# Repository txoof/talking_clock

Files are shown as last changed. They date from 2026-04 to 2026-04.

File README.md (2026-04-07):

# Talking Clock

An accessible clock that announces the time on demand or automatically at regular intervals. Designed to be built from off-the-shelf components and localized to any language that has a [Piper TTS](https://github.com/rhasspy/piper) voice model.

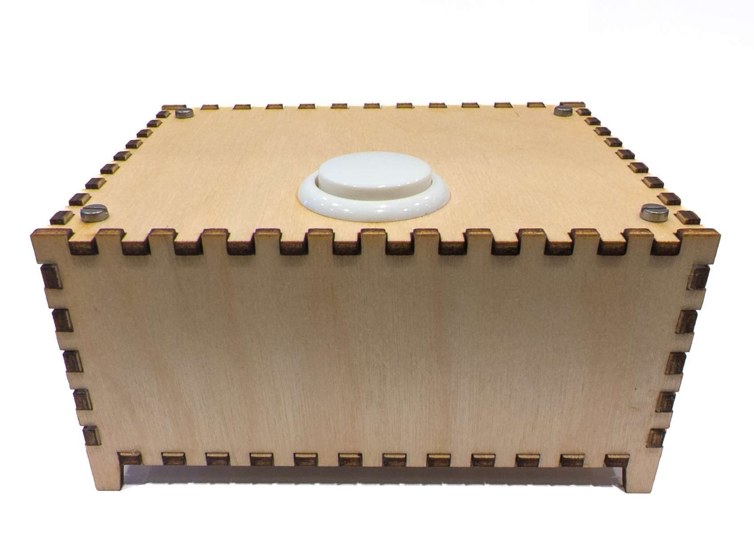
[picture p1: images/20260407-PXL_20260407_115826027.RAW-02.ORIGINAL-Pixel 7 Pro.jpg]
Clock Enclosure


## User Manual

Please see the [End User Manual](./User_Manual.md) for operation instructions.

## Overview

The clock is built around a Raspberry Pi Pico running CircuitPython. Three buttons provide the entire user interface: one to announce the time, and two for navigating settings. All audio is pre-generated and stored on an SD card, making the clock fully offline with no network dependency.

The project has three main components:

| Component | Location | Description |
| --- | --- | --- |
| Firmware | [`./clock_code/`](./clock_code/) | CircuitPython code that runs on the Pico |
| Audio tooling | [`./talking-clock-audio/`](./talking-clock-audio/) | Python CLI for generating and deploying voice packages |
| Hardware | [`./circuit/`](./circuit/) and [`./enclosure/`](./enclosure/) | Bill of materials, wiring, and laser-cut enclosure design |

## Fast Track

This is the shortest path from parts to a working clock. Each step links to the relevant README for full details.

### 1. Assemble the hardware

Build the circuit from the bill of materials and wiring diagram in the [electronics README](./electronics/README.md). The enclosure design is in the [enclosure README](./enclosure/README.md) and is optional -- the clock works without one.

### 2. Install CircuitPython and firmware

Follow the [clock firmware README](./clock_code/README.md) to install CircuitPython 10.x on the Pico, copy the firmware files, and prepare the SD card with the bundled audio assets.

### 3. Deploy a voice package

Voice packages are included in the repository. Connect the SD card to your computer and run:

```bash
cd talking-clock-audio
python -m venv venv
source venv/bin/activate
pip install -e .
tca deploy
```

Select the SD card volume and choose the packages to copy. The default firmware configuration expects a voice package named `en_US_lessac_medium`. See the [talking-clock-audio README](./talking-clock-audio/README.md) for the full workflow including generating packages for other languages.

### 4. First boot

Insert the SD card and power on the clock. The firmware will create a default `config.json` on the SD card automatically. Press ANNOUNCE to hear the time. Hold PLUS or MINUS for 1.5 seconds to open the settings menu and set the correct time.

## Localization

The clock supports any language that has a Piper TTS voice model on Hugging Face. Adding a new language requires creating a YAML phrase configuration file and generating a voice package with the `tca` tool. See the [talking-clock-audio README](./talking-clock-audio/README.md) for the full workflow, including an LLM-assisted tool for building YAML configurations for languages you are not fluent in.

## Repository Structure

```text
talking-clock/
  clock_code/              # CircuitPython firmware and SD card audio assets
  talking-clock-audio/     # tca CLI for generating and deploying voice packages
  electronics/             # Bill of materials, wiring, and schematics
  enclosure/               # Laser-cut enclosure OpenSCAD design and assets
```

## Attributions

### Audio Files

| Asset | Attribution |
| ----- | --- |
| [volume_boop.wav](./clock_code/sd_card/audio_assets/volume_boop.wav) | [546974__finix473__ui_click](https://freesound.org/people/finix473/sounds/546974/) |
| [alarms/accepted-sweet.wav](./clock_code/sd_card/audio_assets/alarms/accepted-sweet.wav) | [akelley6](https://freesound.org/people/akelley6/packs/44231/) |
| [alarms/adventure-harp.wav](./clock_code/sd_card/audio_assets/alarms/adventure-harp.wav) | [akelley6](https://freesound.org/people/akelley6/packs/44231/) |
| [alarms/bell-motif.wav](./clock_code/sd_card/audio_assets/alarms/bell-motif.wav) | [akelley6](https://freesound.org/people/akelley6/packs/44231/) |
| [alarms/sine-aww.wav](./clock_code/sd_card/audio_assets/alarms/sine-aww.wav) | [akelley6](https://freesound.org/people/akelley6/packs/44231/) |
| [alarms/sine-cellular.wav](./clock_code/sd_card/audio_assets/alarms/sine-cellular.wav) | [akelley6](https://freesound.org/people/akelley6/packs/44231/) |
| [alarms/welcome-home-synth.wav](./clock_code/sd_card/audio_assets/alarms/welcome-home-synth.wav) | [akelley6](https://freesound.org/people/akelley6/packs/44231/) |
| [alarms/xd-mewtwo.wav](./clock_code/sd_card/audio_assets/alarms/xd-mewtwo.wav) | [akelley6](https://freesound.org/people/akelley6/packs/44231/) |
| [alarms/xmas-miracle.wav](./clock_code/sd_card/audio_assets/alarms/xmas-miracle.wav) | [akelley6](https://freesound.org/people/akelley6/packs/44231/) |
## License

GPL-3.0-or-later

## Contributing

Contributions are welcome, especially new language configurations, voice model recommendations, hardware improvements, and enclosure designs. Open an issue or pull request on [GitHub](https://github.com/txoof/talking-clock).

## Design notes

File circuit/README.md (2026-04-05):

# Talking Clock Electronics

This document covers the electronic components, wiring, and known hardware gotchas for the Talking Clock project.

- [Talking Clock Electronics](#talking-clock-electronics)
  - [Overview](#overview)
  - [Bill of Materials](#bill-of-materials)
  - [Wiring](#wiring)
  - [Known Hardware Gotchas](#known-hardware-gotchas)

## Overview

The clock is built around a Raspberry Pi Pico (RP2040) running CircuitPython. A DS3231 RTC module keeps accurate time over power cycles. Audio is generated by the Pico and driven through a MAX98357A I2S amplifier to a small full-range speaker. Three buttons provide the user interface. All voice audio and configuration files are stored on an SD card.

All components are off-the-shelf and sourceable from standard electronics suppliers. No custom PCB is required.

## Bill of Materials

### Electronics

| Part | Specifications | Notes | Link |
| ---- | --- | ----- | ---- |
| Raspberry Pi Pico | RP2040 | Pico or Pico W | |
| SPI SD Card Reader | 3.3V-5V Level Shifted | | [TinyTronics 000375](https://www.tinytronics.nl/en/data-storage/modules/microsd-card-adapter-module-3.3v-5v-with-level-shifter) |
| I2C DS3231 RTC Module | | Requires CR2032 battery | [TinyTronics 005849](https://www.tinytronics.nl/en/sensors/time/keyestudio-ds3231-rtc-module-i2c) |
| CR2032 Battery | | For RTC backup power | |
| I2S MAX98357A Amplifier | 3W | Clones available | [Adafruit 3006](https://www.adafruit.com/product/3006) |
| Mono Speaker | 4 ohm 3W full-range | Enclosed speaker has superior sound | |
| Arcade Button | 30mm | Main ANNOUNCE button | [Kiwi Electronics](https://www.kiwi-electronics.com/en/30mm-arcade-button-black-3860) |
| Momentary Push Button Switch | Panel Mount 37x14x14mm | 2x required, PLUS and MINUS | [Conrad.com](https://www.conrad.com/en/p/tru-components-tc-dt310ws-tc-dt310ws-pushbutton-momentary-1-pc-s-1589423.html) |
| 2.54mm Pitch Strip Board | | For VCC/GND bus bar | |
| 2.54mm Pin Headers | 2x9 | Bus bar for VCC and GND | |

## Wiring

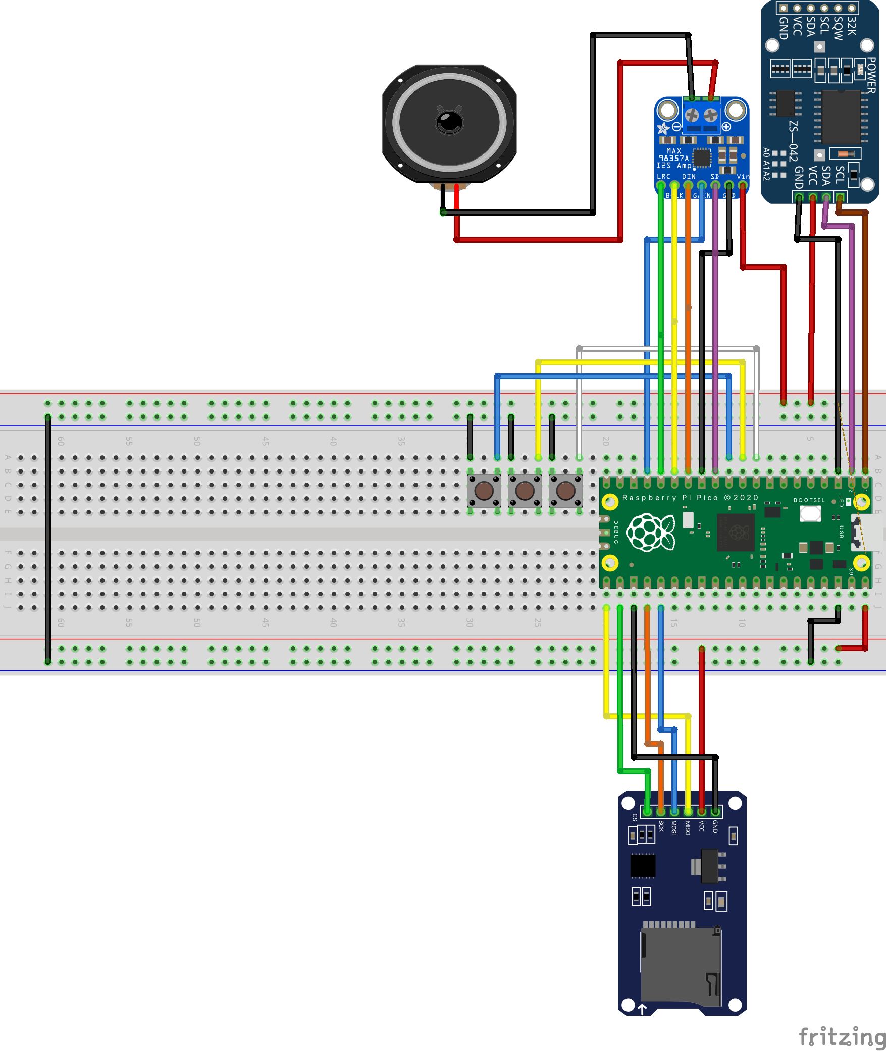
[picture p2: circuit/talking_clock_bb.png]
Bread Board Image


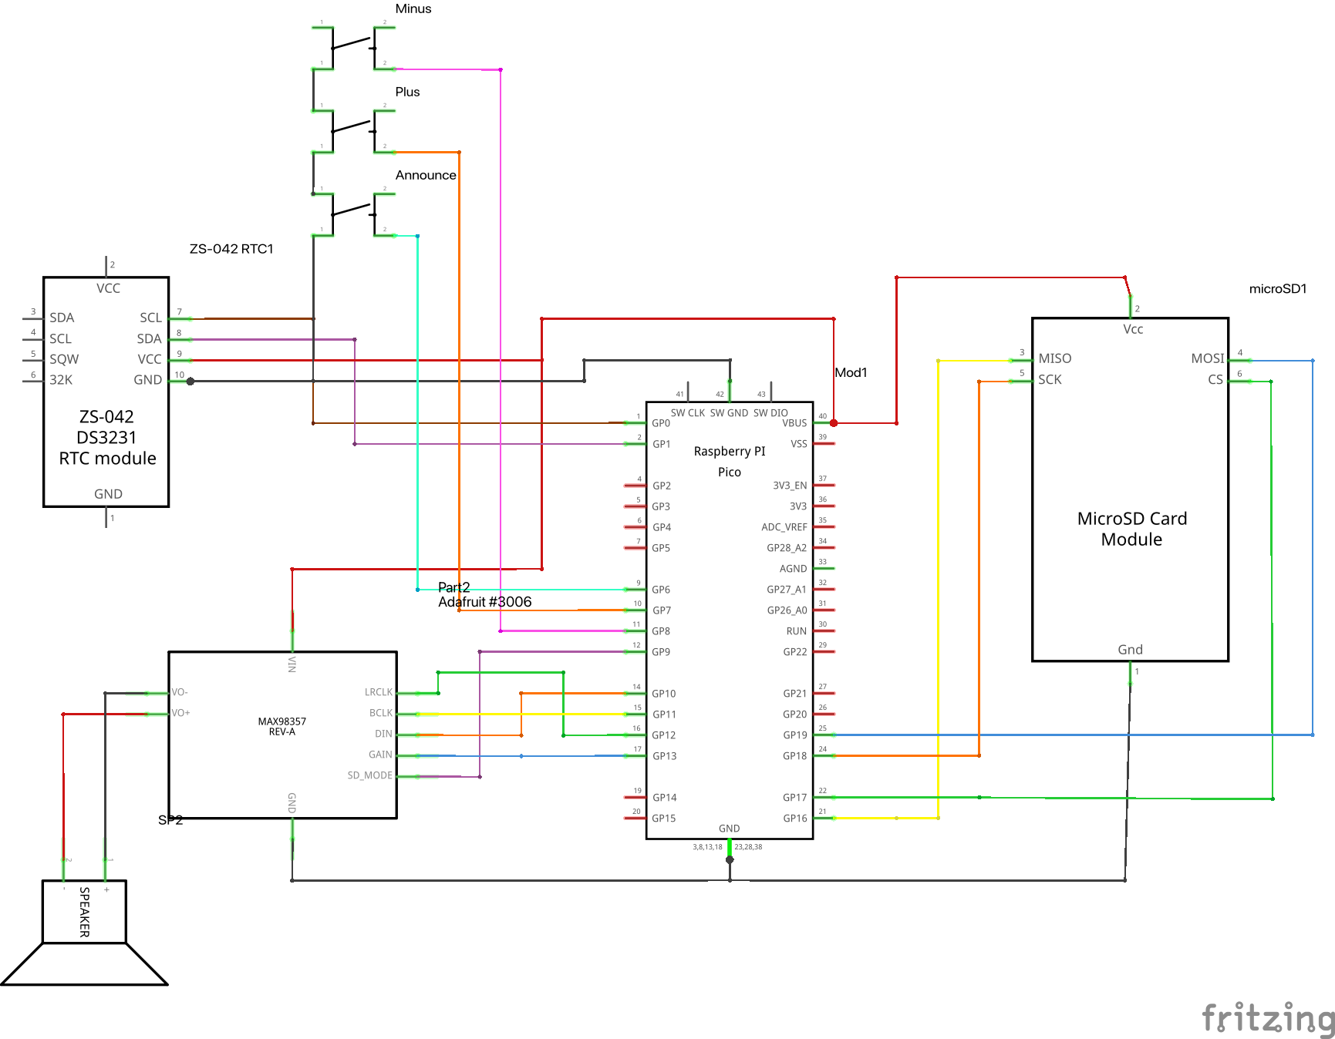
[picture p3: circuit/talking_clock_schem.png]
Wiring Schematic


[Fritzing](https://fritzing.org/download/) [`talking_clock.fzz`](./talking_clock.fzz)

### Pin assignments

| Signal | Pico Pin | Notes |
| --- | --- | ----- |
| I2C SDA (RTC) | GP0 | |
| I2C SCL (RTC) | GP1 | |
| I2S Data | GP10 | MAX98357A DIN |
| I2S Bit Clock | GP11 | MAX98357A BCLK |
| I2S Word Select | GP12 | MAX98357A LRC |
| Amp GAIN | GP13 | Driven high for 9dB gain |
| SD MISO | GP16 | |
| SD CS | GP17 | |
| SD CLK | GP18 | |
| SD MOSI | GP19 | |
| ANNOUNCE Button | GP6 | Pulled up, active low |
| PLUS Button | GP7 | Pulled up, active low |
| MINUS Button | GP8 | Pulled up, active low |
| Amp SD (shutdown) | GP9 | Must be driven high |

### Bus bar

A 2x9 pin header soldered to strip board provides a shared VCC and GND bus for components that do not terminate directly at the Pico. One column carries 3.3V and the other carries GND. The push button switches and any other components requiring a common ground connect here.

## Known Hardware Gotchas

### MAX98357A SD pin must be driven high

The SD pin on the MAX98357A controls the shutdown state of the amplifier. If left floating, the pin state is undefined and the amplifier will intermittently shut down, producing random pops and dropouts that are easy to mistake for a software or speaker problem.

GP9 must be configured as an output and driven high at boot before any audio is played:

```python
sd = digitalio.DigitalInOut(board.GP9)
sd.direction = digitalio.Direction.OUTPUT
sd.value = True
```

### I2C pin assignment

The DS3231 RTC uses I2C on GP0 and GP1. The assignment is SCL on GP1 and SDA on GP0, which is the reverse of what some wiring diagrams show. Using the wrong assignment will cause the RTC to fail silently at boot.

### GAIN pin configuration

The MAX98357A GAIN pin sets the amplifier gain. Leaving it floating selects 9dB gain, which is appropriate for this application. Do not connect GAIN to GND (15dB) or VDD (12dB) unless you have a specific reason to change the gain level.

### Speaker selection

Sensitivity and enclosure matter as much as power rating. A speaker rated at 85 dB/W/m or better in a proper full-range enclosure will sound significantly better than a bare driver of the same wattage. The high-pass filter in the audio generation pipeline removes low-frequency content that small drivers cannot reproduce, but it cannot compensate for a poorly chosen or unenclosed speaker.

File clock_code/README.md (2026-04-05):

# Talking Clock Firmware

This directory contains the CircuitPython firmware for the Talking Clock and all files that need to be deployed to the Pico and SD card.

## Requirements

### CircuitPython

The clock requires CircuitPython 10.x. The firmware was developed and tested against CircuitPython 10.1.4 on the Raspberry Pi Pico (RP2040).

To check the version currently installed on your Pico, connect it via USB and read `boot_out.txt` from the CIRCUITPY drive, or connect with mpremote and run:

```python
import sys
print(sys.version)
```

To install or update CircuitPython, download the UF2 file for the Raspberry Pi Pico from [circuitpython.org](https://circuitpython.org/board/raspberry_pi_pico/) and follow the instructions there.

It is best to prepare the Pico with CircuitPython prior to installing it in the enclosure!

### Libraries

The following Adafruit libraries are required:

```text
adafruit_ds3231==2.4.26
adafruit_bus_device==5.2.15
adafruit_register==1.11.1
```

Pre-compiled `.mpy` versions are included in `./lib/` and should be copied to the `lib/` directory on the CIRCUITPY drive. See the Installation section below.

## File Layout

Files are split between two destinations: the CIRCUITPY drive (the Pico itself) and the SD card.

### What goes on the Pico (CIRCUITPY)

Copy these files and directories to the root of the CIRCUITPY drive:

```text
code.py
menu.py
menu.json
debug_mode.py
pico_rules.py
voices.py
lib/
  adafruit_bus_device/
  adafruit_ds3231.mpy
  adafruit_register/
```

Do not copy `README.md`, `requirements.txt`, `sd_card/`, `libArchive/`, `stubArchive/`, or `__pycache__/` to the Pico.

### What goes on the SD card

The SD card must be formatted as FAT32 with the volume label `TALK-CLOCK`. Copy the contents of `./sd_card/` to the root of the SD card:

```text
audio_assets/
  volume_boop.wav          # played on volume change confirmation
  beep.wav                 # played during button hold-repeat in time setting
  alarms/                  # alarm tone WAV files
    accepted-sweet.wav
    adventure-harp.wav
    bell-motif.wav
    sine-aww.wav
    sine-cellular.wav
    welcome-home-synth.wav
    xd-mewtwo.wav
    xmas-miracle.wav
```

Voice packages are  included in the repository. They can be added to the SD card using `tca deploy`. See [Adding Voice Models](#adding-voice-models) below.

## Installation

### 1. Install CircuitPython

Download the UF2 file for the Raspberry Pi Pico from [circuitpython.org](https://circuitpython.org/board/raspberry_pi_pico/). Hold the BOOTSEL button on the Pico while connecting it via USB. It will mount as a drive called RPI-RP2. Copy the UF2 file to that drive. The Pico will reboot and mount as CIRCUITPY.

### 2. Install libraries

The required libraries are included in `./lib/`. Copy the entire `lib/` directory to the root of the CIRCUITPY drive:

```bash
cp -r ./lib /Volumes/CIRCUITPY/lib
```

Alternatively, install them using [circup](https://github.com/adafruit/circup), Adafruit's CircuitPython library manager:

```bash
pip install circup
circup install adafruit_ds3231 adafruit_bus_device adafruit_register
```

### 3. Copy firmware files

Copy the following files to the root of the CIRCUITPY drive:

```bash
cp code.py menu.py menu.json debug_mode.py pico_rules.py voices.py /Volumes/CIRCUITPY/
```

The Pico will restart automatically when `code.py` is copied or updated.

### 4. Prepare the SD card

Format the SD card as FAT32 and set the volume label to `TALK-CLOCK`. Copy the audio assets to the SD card:

```bash
cp -r ./sd_card/audio_assets /Volumes/TALK-CLOCK/audio_assets
```

Insert the SD card into the clock.

### Adding voice models

The clock requires at least one voice package on the SD card to announce the time. Voice packages are generated from Piper TTS voice models using the `tca` command-line tool included in the `talking-clock-audio/` directory of this repository.

See the [talking-clock-audio README](../talking-clock-audio/README.md) for the full workflow covering downloading voice models, generating audio packages, and deploying them to the SD card.

A minimal setup requires one voice package. The default voice expected by the firmware is `en_US_lessac_medium`. 

## Configuration

The firmware reads configuration from `/sd/config.json` on the SD card. This file is created automatically on first boot with default values if it does not exist. It is updated automatically when settings are changed through the menu.

### config.json reference

| Key | Default | Description |
| --- | --- | --- |
| `volume_step` | `7` | Volume level from 0 (silent) to 10 (maximum) |
| `voice` | `"en_US_lessac_medium"` | Name of the active voice package directory on the SD card |
| `mode` | `"standard"` | Time announcement mode: `operational`, `broadcast`, `standard`, or `casual` |
| `alarm_enabled` | `false` | Whether the alarm is active |
| `alarm_hour` | `7` | Alarm hour in 24-hour format |
| `alarm_minute` | `0` | Alarm minute |
| `alarm_tone` | `"/sd/audio_assets/volume_boop.wav"` | Path to the alarm tone WAV file |
| `announce_interval` | `"off"` | Auto-announce interval: `"off"`, `"hourly"`, `"half"`, or `"quarter"` |

## Using the Clock

### Button interface

The clock has three buttons: ANNOUNCE, PLUS, and MINUS.

| Button | Normal mode | In a menu |
| --- | --- | --- |
| ANNOUNCE | Announce the current time | Confirm selection |
| PLUS (short) | Volume up | Scroll forward |
| MINUS (short) | Volume down | Scroll back |
| PLUS or MINUS (hold 1.5s) | Open settings menu | Exit menu |

Volume changes are confirmed with a short beep and saved automatically after 5.5 seconds of inactivity.

### Menu navigation

Open the menu by holding PLUS or MINUS for 1.5 seconds. The clock announces the name of each menu item as you scroll. Press ANNOUNCE to confirm a selection. Any long press exits the menu.

The menu contains the following items in order:

| Item | Description |
| --- | --- |
| Set time | Set the current hour and minute on the RTC |
| Set alarm | Set the alarm hour and minute |
| Enable alarm | Toggle the alarm on or off |
| Alarm tone | Cycle through available alarm tones |
| Announcement interval | Set auto-announce to off, hourly, half-hourly, or quarterly |
| Time format | Cycle through available announcement modes |
| Voice | Cycle through available voice packages |

The menu closes automatically after 30 seconds of inactivity.

### Setting the time

Open the menu and select "Set time". The clock announces the current hour. Use PLUS and MINUS to adjust, holding for faster scrolling. Press ANNOUNCE to confirm the hour and move to minutes. Press ANNOUNCE again to save and return to normal mode. Time entry times out after 30 seconds of inactivity.

### Debug output

The firmware prints status and diagnostic information to the serial console. Connect via USB and open a serial terminal (115200 baud) or use mpremote to see output:

```bash
mpremote connect auto
```

Useful output includes the current version, loaded voice and mode, RTC time at boot, rule loading results, and any errors encountered during audio playback or SD card access.

## Troubleshooting

**Clock does not boot or CIRCUITPY does not appear**

Check that CircuitPython is installed. Hold BOOTSEL while connecting USB to enter bootloader mode, then reinstall the UF2.

**"SD card mounted" does not appear in serial output**

The SD card is not being detected. Check that the card is formatted as FAT32, fully inserted, and that the SPI wiring is correct. See the electronics README for pin assignments.

**No audio plays**

Check that at least one voice package exists on the SD card and that the `voice` key in `config.json` matches the directory name exactly. Check that the MAX98357A SD pin (GP9) is wired correctly -- see the electronics README for the known hardware gotcha regarding this pin.

**Time is wrong after a power cycle**

The RTC battery may be missing or flat. The DS3231 module requires a CR2032 battery to maintain time when the clock is unpowered. Set the time through the menu after replacing the battery.

**Audio is distorted, buzzes or is clipped**

Regenerate the voice package with adjusted processing settings. See the [talking-clock-audio README](../talking-clock-audio/README.md) for tuning the high-pass filter and soft limiter.

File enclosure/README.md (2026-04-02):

# Prototype Clock Enclosure

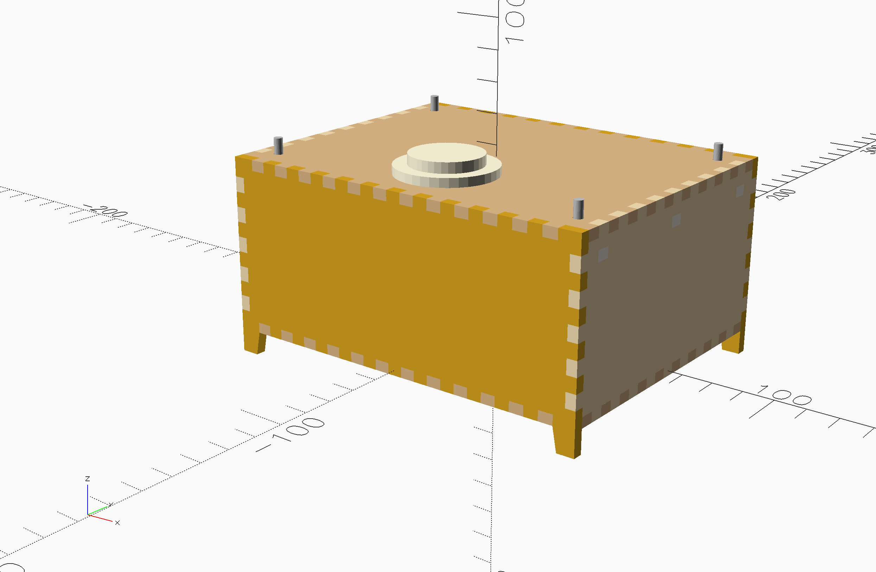
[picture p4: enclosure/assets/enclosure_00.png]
Clock Enclosure Rendering

Speaking Clock Enclosure

The prototype enclosure can be laser cut and assembled only with glue and some basic tools. The design is not beginner friendly and is a starting point for future designers.

**NOTE:** The [`clock.scad`](./clock.scad) file that is provided is set up for a 3D view. The front and top panels are commented out. This is to aide in visualizing placement of components. The missing panels in the 3D rendering will not affect the rendering of the 2D SVG for cutting.

## Laser Cut Enclosure

This model is provided as a customizable OpenSCAD model. It can be customized to work with any thickness plywood, but works best with 3.5-4.0mm wood. Switch openings, speaker grill and other features are all customizable. See the relevant headings in the OpenSCAD code.

Before cutting this, check your material thickness and update the material thickness under the *Enclosure Dimensions* heading. All values are provided in millimeters.

To prepare for laser cutting do the following:

1. Adjust the material thickness value either in the code or the [OpenSCAD Customizer](https://en.wikibooks.org/wiki/OpenSCAD_User_Manual/Customizer)
2. Set rendering mode `three d` to `0` 
3. In the OpenSCAD interface, choose **Design > Render** to produce a valid, exportable 2D object
4. Finally save the design as an SVG with **File > Export > SVG**

The resulting SVG file has a 20x10 mm benchmark rectangle in the lower right corner (Quadrant IV) that is useful for verifying that the SVG was produced with appropriate scaling.

## Assembly

### Materials

| Material | Qty | Purpose | Notes |
| --- | --- | --- | --- |
| M3x16mm Bolts | 4 | Securing Lid | This is based on a material thickness of 4mm |
| M3x10mm bolts | 2 | Securing Speaker | |
| M3 Nuts | 6 | Securing Lid and Speaker | |
| 4mm Laser Safe Ply | | | |
| Wood Glue | | | |
| 2.5mm screws | | | |
| 2.54 pitch strip board | | | |
| Dupont Headers | 2x9 | Bus Bar for VCC and GND  | Use fiberglass copper strip board with continuous strips |

### Procedure

#### Make a Bus Bar

You will need a 9x2 2.54 bus bar for VCC and Ground connections.

Create a bus bar using 2.54 pitch strip board with two columns of 9 pins. one side of the bus is for all 5v VCC connections and the other for ground connections that do not terminate at the Pico (e.g. push button switches).

#### Make Nut Sandwiches

Make two "nut sandwiches" using two long thin pieces with round holes and one long thin piece with two m3 sized holes and fingers.

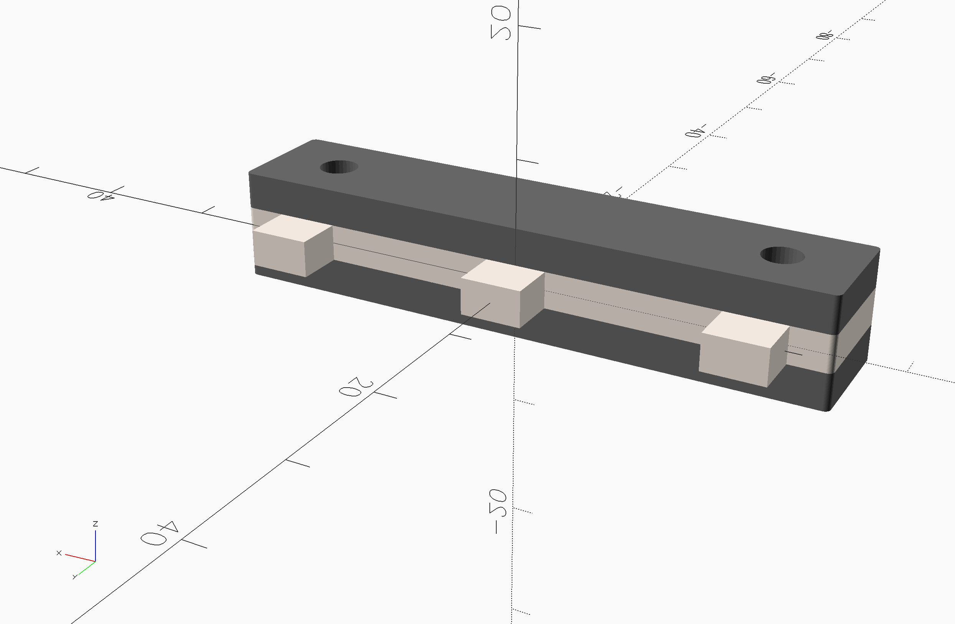
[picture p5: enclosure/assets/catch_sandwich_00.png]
Catch Sandwich Rendering


1. Spread glue on one of the pieces with round holes
2. Add the piece with hexagonal holes and drop in an m3 nut, taking care not to get glue into the threads
3. Spread glue on the top of the middle layer and add the top layer
4. While the glue is still wet, use bolts through the holes to keep the pieces aligned
5. Clamp the pieces together using additional nuts, or a clamp
6. Set aside to dry

#### Assemble Case

1. Drill holes for speaker bolts if necessary
2. Apply glue to fingers for sides, bottom, front and back. DO NOT GLUE LID!
3. Use the small rectangular plates for mounting the various IC boards using 2.5mm screws
4. Glue the various IC boards inside the enclosure in the approximate locations shown
5. Bolt or secure speaker into case as appropriate
6. Take care to align the Pi Pico with the opening in the rear and the SD card with the card OUTSIDE the enclosure
7. Glue the Nut Sandwiches into the three holes on the top of the left and right sides
8. Secure the lid by threading a bolt through the lid and into the captive nuts

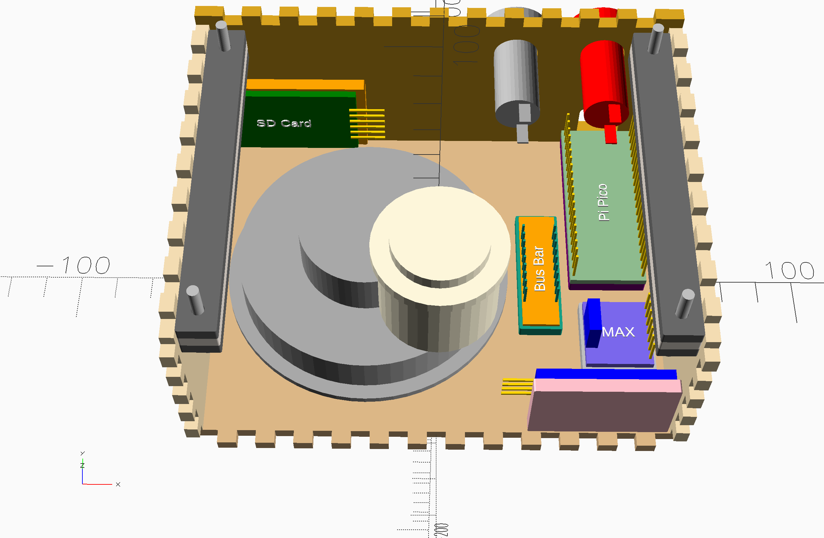
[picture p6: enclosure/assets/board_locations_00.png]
Board Location Rendering


## Assemble the Wiring

See the circuit diagrams for further details regarding wiring.

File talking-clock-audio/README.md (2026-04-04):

# Talking Clock Audio

A command-line tool for generating multilingual time phrase audio files for the Talking Clock project.

- [Talking Clock Audio](#talking-clock-audio)
  - [Requirements](#requirements)
  - [Installation](#installation)
  - [Quick Start](#quick-start)
  - [Generating a Voice Package](#generating-a-voice-package)
  - [Audio Sample Requirements](#audio-sample-requirements)
  - [Adding a New Language](#adding-a-new-language)
  - [Building a YAML configuration with an LLM](#building-a-yaml-configuration-with-an-llm)
  - [Deploying to the Clock](#deploying-to-the-clock)
  - [CLI Reference](#cli-reference)
  - [Project Structure](#project-structure)
  - [Audio Debug Mode](#audio-debug-mode)
  - [License](#license)
  - [Contributing](#contributing)
  - [Acknowledgments](#acknowledgments)
  - [Support](#support)

This package uses Piper TTS to synthesize spoken time announcements from YAML-defined phrase rules. It produces audio packages ready to deploy to the clock's SD card, along with the compiled rule files the Pico firmware uses to select and sequence audio at runtime.

## Requirements

- Python 3.11 or 3.12 (Python 3.14 not yet supported by piper-tts)
- piper-tts
- huggingface-hub
- pyyaml
- click
- questionary
- pycountry

See `pyproject.toml` for the complete dependency list.

## Installation

Install the talking clock audio (`tca`) command in a local virtual environment.

```bash
git clone https://github.com/txoof/talking-clock.git
cd talking-clock/talking-clock-audio
python -m venv venv
source venv/bin/activate
pip install -e .
```

## Quick Start

The minimal path from a fresh install to deploying audio on the clock's SD card.

This walkthrough uses the english US (`en_US`) "lessac" voice as an example. Substitute your preferred locale and voice as needed.

### 1. Download a voice model

**List Available Models on Hugging Face**

```bash
$ tca list-models --remote | less

Found 152 voices in 45 locales:

ar_JO - Arabic (Jordan):
  ar_JO/kareem/low
  ar_JO/kareem/medium

bg_BG - Bulgarian (Bulgaria):
  bg_BG/dimitar/medium

...
en_GB - English (United Kingdom):
  en_GB/alan/low
  en_GB/alan/medium
  en_GB/alba/medium
  en_GB/aru/medium
  en_GB/cori/high
  en_GB/cori/medium
  en_GB/jenny_dioco/medium
  en_GB/northern_english_male/medium
  en_GB/semaine/medium
  en_GB/southern_english_female/low
  en_GB/vctk/medium

en_US - English (United States):
  en_US/amy/low
  en_US/amy/medium
  en_US/arctic/medium
  en_US/bryce/medium
  en_US/lessac/high
  en_US/lessac/low
  en_US/lessac/medium
  en_US/libritts/high
  en_US/libritts_r/medium
  en_US/sam/medium
...
```

**Download and Cache a Model**

```bash
tca get-model --locale en_US --voice lessac --quality medium
```

The files are cached in `./models`.

### 2. Generate the audio package

This will generate `.wav` files using the selected voice model.

```bash
tca generate --yaml time_phrases_en_US.yaml --model ./models/en/en_US/lessac/medium/en_US-lessac-medium.onnx
```

### 3. Validate the output

This step displays some time phrases in using the defined rules allowing a visual and audio verification that the rules have been applied correctly.

```bash
tca validate --yaml time_phrases_en_US.yaml
```

Review the sample phrases for each mode. Check that the `Examples: OK` line appears for all modes.

### 4. Prepare the SD card

Use an SD card with at least 1GB of storage. Format the SD card as FAT32 and set the volume label to `TALK-CLOCK`. The volume lable is not required, but makes deploying easier.

### 5. Deploy audio to the clock

This will copy the appropriate files to the SD card. Make sure the SD card is mounted and available.

```bash
tca deploy
```

Select `TALK-CLOCK` from the volume list. Select the packages to copy. Insert the SD card into the clock.

## Generating a Voice Package

A voice package is a directory containing all the audio files and compiled rule files that are needed for a voice and a locale. Voice packages support up to four different "modes". The modes, operational, broadcast, standard and casual, are different ways of telling time in the selected language. Operational is typically used by the military and in aviation where ambiguity with time is unacceptable. Broadcast is the mode used often in airports, train stations and on news broadcasts where ambiguity is discouraged. Standard mode is typically used in semi-formal settings such as offices and schools. Casual mode is used on the street, among friends and family where precision is not crucial.

American English Example:

| Time | Mode | Phrase |
| --- | --- | --- |
| 8:30 AM | Operational | oh eight thirty |
| 8:45 PM | Operational | twenty fortyfive |
| 9:27 AM | Broadcast | nine twenty seven A.M. |
| 6:15 PM | Broadcast | six fifteen P.M. |
| 4:00 AM | Standard | four o' clock |
| 4:00 PM | Standard | four o' clock |
| 7:12 AM | Casual | quarter after seven |
| 9:28 PM | Casual | half past nine |

Voice packages are generated using a YAML file that contains all of the relevant words and rules required for building time phrases.

All modes are share a single set of audio files. Per-mode rules are stored separately within a `rules` sub directory. 

Generated packages are written to `./audio/` by default:

```text
en_US_lessac_medium
├── audio
│   ├── interval_half.wav
│   ├── interval_hourly.wav
...
│   └── words_zero.wav
├── generation_info.json
├── rules
│   ├── broadcast_rules.json
│   ├── casual_rules.json
│   ├── operational_rules.json
│   └── standard_rules.json
└── vocab.json
```

### Generate a package

```bash
tca generate --yaml time_phrases_en_US.yaml --model ./models/en/en_US/lessac/medium/en_US-lessac-medium.onnx
```

If either option is omitted, `tca generate` will prompt you to select from available YAML files and downloaded models.

The output directory is derived from the model filename: `audio/<locale>_<voice>_<quality>/`

To write to a different location:

```bash
tca generate --yaml time_phrases_en_US.yaml --model <path> --output-dir ./my_output
```

To overwrite an existing package without confirmation:

```bash
tca generate --yaml time_phrases_en_US.yaml --model <path> --force
```

### Audio processing options

The generator applies two processing steps to every WAV file to improve intelligibility on the small speaker used in the clock.

**High-pass filter** removes low-frequency content that small speakers cannot reproduce cleanly. The default cutoff is 300Hz.

**Soft limiter** prevents clipping on loud peaks. The default threshold is 16000 (out of 32767).

These defaults work well for a standard 4-ohm 3-watt full-range driver with no enclosure. Adjust them if your speaker sounds distorted or muffled.

```bash
# Adjust high-pass filter cutoff
tca generate --yaml <file> --model <path> --highpass-cutoff 500

# Adjust soft limiter threshold
tca generate --yaml <file> --model <path> --speaker-threshold 24000

# Disable high-pass filter
tca generate --yaml <file> --model <path> --highpass-cutoff 0

# Disable soft limiter
tca generate --yaml <file> --model <path> --speaker-threshold 32767

# Disable all processing (raw TTS output)
tca generate --yaml <file> --model <path> --highpass-cutoff 0 --speaker-threshold 32767
```

### Troubleshooting audio quality

**Audio sounds clipped or distorted on the speaker**

Lower the soft limiter threshold. Start at 24000 and work downward until clipping disappears:

```bash
tca generate --yaml <file> --model <path> --speaker-threshold 24000
```

**Audio sounds muffled or boomy**

Raise the high-pass filter cutoff. Try 500Hz for small drivers:

```bash
tca generate --yaml <file> --model <path> --highpass-cutoff 500
```

**Audio sounds thin or tinny**

Lower the high-pass filter cutoff, or disable it entirely if your speaker handles bass well:

```bash
tca generate --yaml <file> --model <path> --highpass-cutoff 150
```

**Audio quality is fine on headphones but poor on the clock speaker**

The speaker in the clock enclosure may have different characteristics than your test speaker. Use the `tca debug` command to generate test audio with multiple processing variants and compare them directly on the hardware. See `tca debug --help` for details.

### Validate a package

After generating, run validate to confirm that the compiled rules produce the expected spoken phrases:

```bash
tca validate --yaml time_phrases_en_US.yaml
```

This compiles the rules, generates sample phrases for a set of representative times, and checks them against the `examples:` block in the YAML. A passing result looks like:

```Text
Mode: casual
========================================================
  Time     Label        Phrase
  ------- ----------- -----------------------------------
  00:00  midnight     midnight
  08:09  08:09        eight oh nine
  ...

  Examples: OK (5 checked)

========================================================
Result: OK
```

Any mismatch between the generated phrase and the expected phrase in the `examples:` block is reported as a warning. Fix the rules in the YAML and re-run until all modes pass.

## Audio Sample Requirements

All WAV files must match the mixer configuration exactly. Files that do not match will fail to play silently or raise a `ValueError` at runtime on the Pico.

The `tca generate` command always produces files in the correct format. This section is only relevant if you are sourcing audio files from another tool or converting existing files.

### Required format

| Property | Value |
| --- | ----- |
| Format | PCM WAV (uncompressed) |
| Sample rate | 22050 Hz |
| Channels | Mono (1 channel) |
| Bit depth | 16-bit signed |

### Converting files with ffmpeg

Convert a single file:

```bash
ffmpeg -i input.wav -ar 22050 -ac 1 -sample_fmt s16 output.wav
```

Convert all WAV files in the current directory, writing results to a `converted/` subdirectory:

```bash
mkdir -p converted
for f in *.wav; do
    ffmpeg -i "$f" -ar 22050 -ac 1 -sample_fmt s16 "converted/$f"
done
```

### Verifying a file

```bash
ffprobe -v error -show_entries stream=sample_rate,channels,sample_fmt -of compact input.wav
```

Expected output:

```text
sample_rate=22050|channels=1|sample_fmt=s16
```

## Adding a New Language

Adding a new language requires three things: a YAML phrase configuration file, a downloaded Piper TTS voice model for that language and a run of `tca generate`.

### 1. Find a voice model

List available models on Hugging-Face:

```bash
tca list-models --remote | less
```

To find German voices:

```bash
tca list-models --remote | grep de_DE
```

Download the model:

```bash
tca get-model --locale de_DE --voice thorsten --quality medium
```

### 2. Create a phrase configuration

Copy the [template](./time_phrases_template.yaml) as a starting point:

```bash
cp time_phrases_template.yaml time_phrases_de_DE.yaml
```

Edit the file to fill in translations and adapt the casual mode rules to your language's conventions. Place the completed template in the `time_formats` directory.

The template contains comments explaining every section. Pay particular attention to the `casual` mode, which is the most language-specific. In particular, note that some languages (including Dutch and German) express the half hour relative to the upcoming hour rather than the past hour. "Half drie" in Dutch means 2:30, not 3:30.

For complex languages or if you are not a native speaker, use the LLM-assisted workflow described below.

### 3. Validate the configuration

```bash
tca validate --yaml time_phrases_de_DE.yaml
```

Work through any warnings until all modes report `Examples: OK`.

### 4. Generate the audio package

```bash
tca generate --yaml time_phrases_de_DE.yaml --model ./models/de/de_DE/thorsten/medium/de_DE-thorsten-medium.onnx
```

### 5. Deploy to the clock

```bash
tca deploy
```

## Building a YAML configuration with an LLM

To help build the YAML file, the repository includes a system prompt that coaches an LLM through collecting the information needed to produce a valid YAML file.

The prompt is in [`LOCALE_BUILDER_PROMPT.md`](./LOCALE_BUILDER_PROMPT.md). It walks the LLM through:

- vocabulary collection
- time-telling conventions for each mode
- casual mode minute boundaries
- the `examples:` block needed for `tca validate`

The prompt is designed to be set as a **system prompt** rather than pasted as a regular message. See `LOCALE_BUILDER_PROMPT.md` for setup instructions for ChatGPT, Claude, and local LLMs.

After the LLM produces a YAML file, always run:

```bash
tca validate --yaml time_phrases_LOCALE.yaml
```

LLMs occasionally make errors in the `minute_map` or get casual mode conventions wrong for languages with non-obvious conventions. The validate command will catch these before you generate audio.

## Deploying to the Clock

The `tca deploy` command copies generated voice packages to a mounted SD card and manages what is already on the card.

### Prepare the SD card

Format the SD card as FAT32. Set the volume label to `TALK-CLOCK`. The label is not required but makes it easier to identify the card in the volume list. Any SD card with at least 1GB of storage is sufficient.

### Run tca deploy

Insert and mount the SD card, then run:

```bash
tca deploy
```

**Step 1: Select a volume**

The command lists all mounted volumes and asks you to pick one:

```text
? Select SD card volume:
  /Volumes/TALK-CLOCK
  /Volumes/Backup Drive
  /Volumes/CIRCUITPY
```

**Step 2: Review the summary**

After selecting a volume, a summary shows what is available locally and what is already on the card:

```text
Source:  /Users/aaron/talking-clock-audio/audio
Target:  /Volumes/TALK-CLOCK

LOCAL PACKAGES                                   ON SD CARD
--------------------------------------------------------------------------------
en_US_lessac_medium      (lessac, medium, 2026-04-04)   (not present)
en_US_amy_medium         (amy, medium, 2026-04-04)      (amy, medium, 2026-03-12)
nl_NL_pim_medium         (pim, medium, 2026-04-04)      (pim, medium, 2026-04-04)
```

Colour coding:

- Cyan: present locally only, not yet on the card
- Yellow: present both locally and on the card
- Green: present on the card only, not in the local audio directory

**Step 3: Select packages to copy**

A checkbox menu lists all local packages. Use the arrow keys to move and space to select. Press enter to confirm:

```text
? Select packages to copy to SD card:
  [ ] en_US_lessac_medium    (lessac, medium, 2026-04-04)
  [x] en_US_amy_medium       (amy, medium, 2026-04-04)
  [ ] nl_NL_pim_medium       (pim, medium, 2026-04-04)
```

If a selected package already exists on the card you will be asked to confirm before it is overwritten.

**Step 4: Delete packages from the card**

After copying, the command asks whether you want to delete anything from the card:

```text
? Would you like to delete any packages from the SD card?
```

If you answer yes, a checkbox menu lists everything currently on the card. Each selected package requires a separate confirmation before it is deleted:

```text
? Permanently delete 'nl_NL_rdh_medium' from SD card? (y/N)
```

Only directories that are valid voice packages can be deleted through this command.

### Expert mode

If you already know the target path, skip the volume selection prompt:

```bash
tca deploy --target /Volumes/TALK-CLOCK
```

To scan a different local audio directory:

```bash
tca deploy --source-dir ./my_audio --target /Volumes/TALK-CLOCK
```

To skip overwrite confirmation when copying:

```bash
tca deploy --target /Volumes/TALK-CLOCK --force
```

Full expert mode:

```bash
tca deploy --source-dir ./audio --target /Volumes/TALK-CLOCK --force
```

## CLI Reference

All commands support interactive mode (prompts for missing options) and expert mode (all options supplied as flags). Running any command without flags will prompt for required inputs. Every command prints the full expert-mode command at the end of a successful run for easy repetition.

Global flags apply to all commands:

```bash
tca --verbose <command>    # show debug logging
tca --quiet <command>      # suppress all output except errors
tca <command> --help       # show full help for a command
```

### list-models

Lists available voice models. Defaults to showing locally downloaded models.

```bash
tca list-models                              # list local models
tca list-models --remote                     # list all models on Hugging Face
tca list-models --local --model-dir ./models # specify model directory
```

### get-model

Downloads a voice model from Hugging Face and caches it in `./models/`.

```bash
tca get-model                                              # interactive
tca get-model --locale en_US --voice lessac --quality medium
tca get-model --locale nl_NL --voice pim --quality medium
tca get-model --model-dir /path/to/models --locale en_US --voice lessac --quality medium
```

### validate

Compiles the rules from a YAML file, generates sample phrases for ten representative times, and checks them against the `examples:` block. Optionally plays the generated audio sequences if a matching package exists in `./audio/`.

```bash
tca validate                                 # interactive
tca validate --yaml time_phrases_en_US.yaml
```

### generate

Generates a complete voice package from a YAML phrase file and a downloaded voice model. All modes are generated in a single run and share one set of WAV files.

```bash
tca generate                                 # interactive
tca generate --yaml time_phrases_en_US.yaml --model ./models/en/en_US/lessac/medium/en_US-lessac-medium.onnx
tca generate --yaml time_phrases_en_US.yaml --model <path> --output-dir ./my_output
tca generate --yaml time_phrases_en_US.yaml --model <path> --force
tca generate --yaml time_phrases_en_US.yaml --model <path> --highpass-cutoff 500
tca generate --yaml time_phrases_en_US.yaml --model <path> --speaker-threshold 24000
tca generate --yaml time_phrases_en_US.yaml --model <path> --highpass-cutoff 0 --speaker-threshold 32767
```

| Flag | Default | Description |
|---|---|---|
| `--yaml` | prompt | Path to locale YAML file |
| `--model` | prompt | Path to `.onnx` voice model |
| `--output-dir` | `audio/<locale>_<voice>_<quality>` | Output directory |
| `--force` | off | Overwrite existing files without confirmation |
| `--highpass-cutoff` | 300 | High-pass filter cutoff in Hz. Set to 0 to disable |
| `--speaker-threshold` | 16000 | Soft limiter threshold (0-32767). Set to 32767 to disable |

### deploy

Copies generated voice packages to a mounted SD card and manages packages already on the card. See the Deploying to the Clock section for a full walkthrough.

```bash
tca deploy                                               # interactive
tca deploy --target /Volumes/TALK-CLOCK
tca deploy --source-dir ./audio --target /Volumes/TALK-CLOCK
tca deploy --source-dir ./audio --target /Volumes/TALK-CLOCK --force
```

| Flag | Default | Description |
|---|---|---|
| `--source-dir` | `./audio` | Local directory to scan for voice packages |
| `--target` | prompt | Path to mounted SD card volume |
| `--force` | off | Skip overwrite confirmation when copying |

### debug

Generates speaker test audio from a debug YAML configuration. Produces one subdirectory per variant, each containing a label file and one WAV per test sentence. All sentences are normalized to a fixed peak before processing so that filter and limiter variants can be compared fairly on the hardware.

```bash
tca debug --model <path>                                 # uses tests/speaker_test.yaml
tca debug --yaml tests/speaker_test.yaml --model <path>
tca debug --yaml tests/speaker_test.yaml --model <path> --output-dir ./audio/debug
tca debug --yaml tests/speaker_test.yaml --model <path> --force
```

| Flag | Default | Description |
|---|---|---|
| `--yaml` | `tests/speaker_test.yaml` | Path to debug configuration YAML |
| `--model` | prompt | Path to `.onnx` voice model |
| `--output-dir` | `./audio/debug` | Output directory for test audio |
| `--force` | off | Overwrite existing files without confirmation |

## Project Structure

```text
talking-clock-audio/
  src/
    talking_clock_audio/
      __init__.py              # package initialisation and logging setup
      cli.py                   # command-line interface (tca commands)
      deploy.py                # SD card deployment logic
      tts_generator.py         # Piper TTS audio generation and speaker processing
      rules_generator.py       # compiles locale YAML into runtime JSON rule files
      phrase_generator.py      # evaluates compiled rules to produce audio sequences
      pico_rules.py            # on-device rule evaluation (also used by validate)
      debug_generator.py       # speaker test audio generation
      voice_manager.py         # Hugging Face voice model listing and download
  tests/
    speaker_test.yaml          # default debug configuration
    test_phrase_generator.py
    test_rules.py
    test_voice_manager.py
    test_voice_scan.py
  time_formats/
    time_phrases_en_GB.yaml    # British English locale configuration
    time_phrases_en_US.yaml    # American English locale configuration
    time_phrases_nl_NL.yaml    # Dutch locale configuration
  time_phrases_template.yaml   # template for adding a new language
  LOCALE_BUILDER_PROMPT.md     # LLM system prompt for building locale YAML files
  pyproject.toml               # package configuration and dependencies
  README.md                    # this file
```

## Audio Debug Mode

The clock has a built-in speaker test mode for comparing audio processing variants directly on the hardware. This is the most reliable way to tune the high-pass filter and soft limiter settings for a specific speaker, since the clock enclosure and amplifier circuit both affect the final sound.

### Generate test audio

The `tca debug` command generates a set of WAV files from a [debug YAML](./tests/speaker_test.yaml) configuration. Each variant produces a label file followed by one WAV per test sentence, all processed with the variant's filter and limiter settings.

```bash
tca debug --model ./models/en/en_US/lessac/medium/en_US-lessac-medium.onnx
```

This uses `tests/speaker_test.yaml` by default and writes output to `./audio/debug/`.

### Copy debug audio to the SD card

Copy the entire `debug/` directory to the root of the SD. The clock expects the debug audio at `/sd/debug/` on the mounted filesystem.

Using the Finder, File Manager, or command line:

```bash
cp -r ./audio/debug /Volumes/TALK-CLOCK/debug
```

Eject and insert the SD card into the clock.

### Enter debug mode

Debug mode is entered by holding the ANNOUNCE button during a cold boot or soft boot from `mpremote`. A reboot can be triggered in two ways.

**Power cycle:** disconnect and reconnect power to the clock while holding ANNOUNCE.

**Using mpremote:** [mpremote](https://docs.micropython.org/en/latest/reference/mpremote.html) is a command-line tool for interacting with MicroPython and CircuitPython devices over USB. Connect the Pico via USB, then run:

```bash
mpremote connect auto
```

Once connected, press `Ctrl+D` to perform a soft reboot while holding the ANNOUNCE button on the clock.

### Navigating debug mode

In debug mode the clock loads variant directories from `/sd/debug/` in alphabetical order.

| Button | Action |
| --- | --- |
| ANNOUNCE | play all files in the current variant in order |
| PLUS | next variant |
| MINUS | previous variant |

Each variant plays its label file first so you can identify which settings you are hearing, followed by the test sentences. Press PLUS or MINUS at any point to interrupt playback and move to another variant.

To exit debug mode, reboot by unplugging or using ctrl+D in `mpremote`. Do not hold down the ANNOUNCE button during reboot.

## License

GPL-3.0-or-later

## Contributing

Contributions welcome! Especially:

- New language configurations
- Voice model recommendations
- Bug fixes and improvements
- Documentation improvements

## Acknowledgments

- [Piper TTS](https://github.com/rhasspy/piper) for high-quality offline text-to-speech
- [Hugging Face](https://huggingface.co/rhasspy/piper-voices) for hosting voice models
- The broader maker community for hardware designs and CircuitPython libraries

## Support

For issues, questions, or contributions, please open an issue on GitHub.

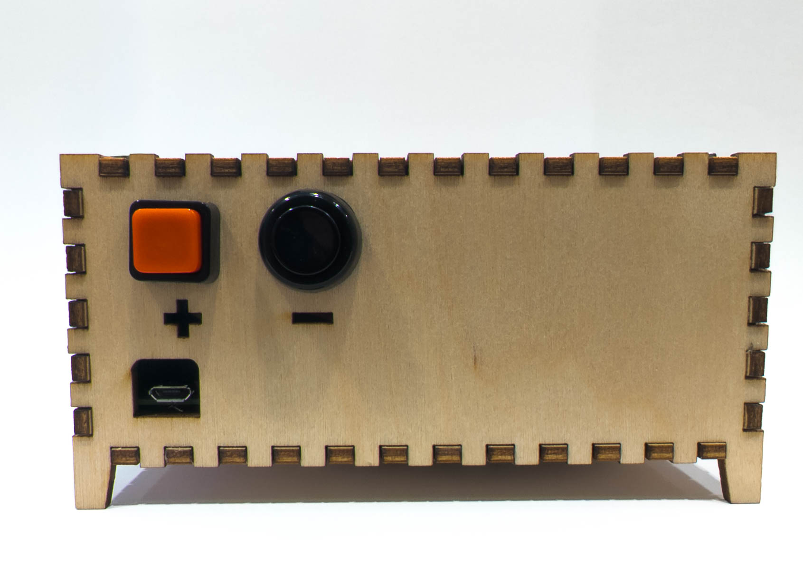
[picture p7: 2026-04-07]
images/20260407-PXL_20260407_115804065.RAW-02.ORIGINAL-Pixel 7 Pro.jpg

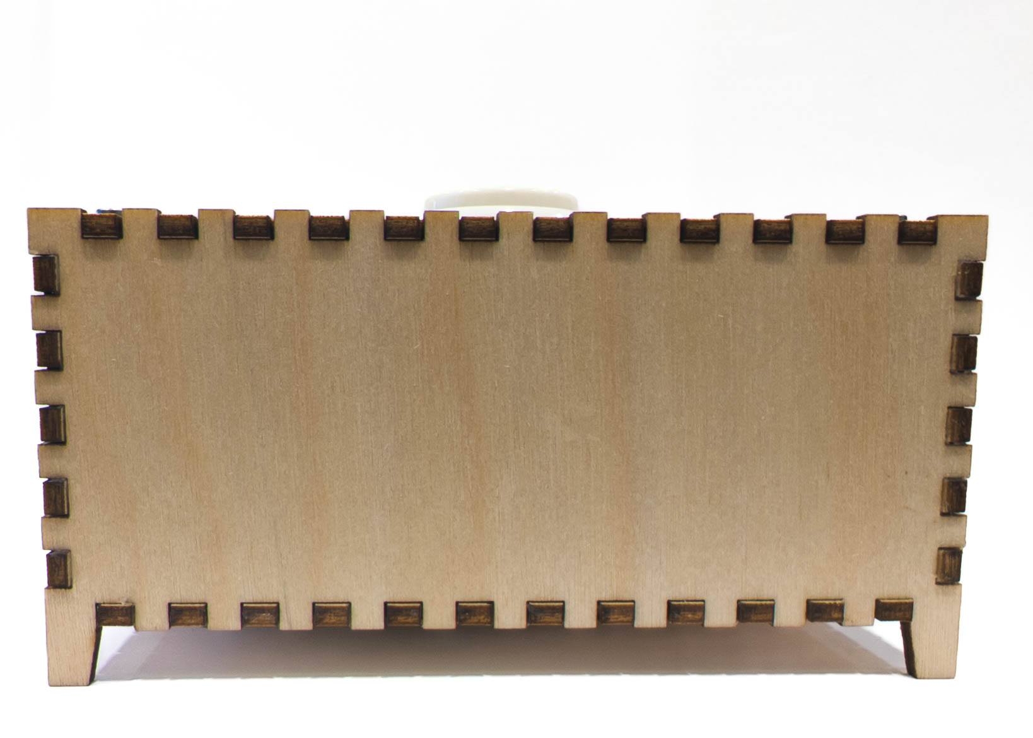
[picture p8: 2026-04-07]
images/20260407-PXL_20260407_115815577.RAW-02.ORIGINAL-Pixel 7 Pro.jpg

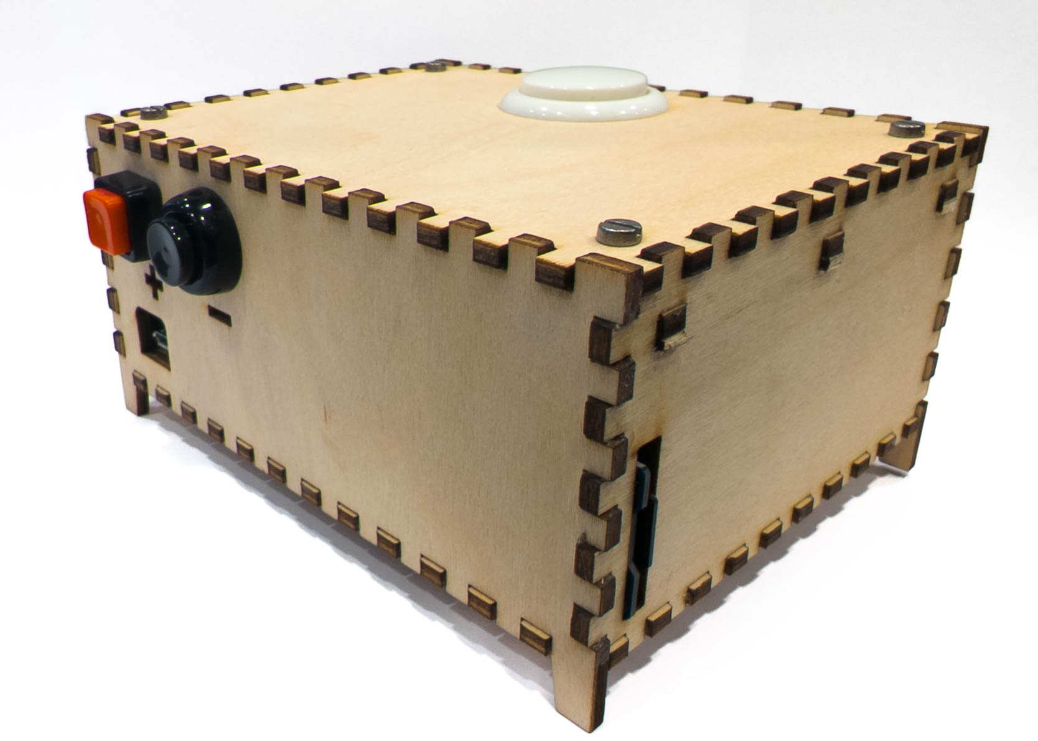
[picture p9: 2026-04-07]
images/20260407-PXL_20260407_115906119.RAW-02.ORIGINAL-Pixel 7 Pro.jpg

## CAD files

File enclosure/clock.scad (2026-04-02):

use <./scad_libraries/finger_joint_box.scad>
use <./scad_libraries/clock_components.scad>
use<./scad_libraries/cone_speaker.scad>
use<./scad_libraries/speaker_grill.scad>
use<./scad_libraries/arcade_button.scad>
use<./scad_libraries/fasteners.scad>
use<./scad_libraries/cone_speaker.scad>


/* [Rendering Setup] */

three_d = 1;
alpha = 0.2;

/* [Enclosure Dimensions] */
// Average material thickness (mm)
material = 3.5;
// Finger Joint Width in (mm)
finger = 5;

// Exterior Width
case_x = 130;
// Exterior Depth
case_y = 102;
// Exterior Height
case_z = 58; 

/* [Font] */
font = "Impact";


/* [USB Port] */
// Port X width
usb_port_x = 12;
// port Z height
usb_port_z = 10.5;

/* [Speaker] */
// box speaker
speaker_dim = [50, 45, 22];
// mounting ears
ears=true;
// ear outer dia
ear_od=8;
// ear height
ear_h=4;

/* [Cone Speaker] */
cone_dia = 78;
cone_magnet_dia = 36;
cone_height = 27;

/* [MAX98357A Amp] */
max_x = 18;
max_y = 19;
max_z = 2;
terminal_h = 10;

/* [Real Time Clock] */
// Real time Clock X
rtc_x= 35;
// Real time Clock Y
rtc_y = 22;
// Real time clock Z
rtc_z = 6.5;

/* [SD Card Reader] */
sd_x = 42;
sd_y = 24; 
sd_z = 2;
sd_card_clearance = 4.5;

/* [Bus Bar] */
bus_bar_x = 35;
bus_bar_y = 10;
bus_bar_z = 2;
bus_bar_pin_col = 9;

/* [Pi Pico] */
// Pico X Dimensions
pico_x = 51.5;
// Pico Y Dimensions
pico_y = 21; 
// Pico Z Dimensions (board)
pico_z = 2;


/* [Settings Buttons] */
set_body_z = 32.5;
set_body_d = 12;
set_button_z = 3;
set_flange_z = 6.5;
set_flange_d = 19;
set_button_d = 12;
set_contact_x = 3;
set_contact_z = 6;


/* [Announcement Button] */
ann_body_z=29.5;
ann_body_d=30;
ann_button_z=3.5;
ann_flange_z=3;
ann_flange_d=33.3;
ann_button_d=24;
ann_contact_x=3;
ann_contact_z=9.5;

/* [Hidden] */

// convenience array Length, Depth, Height
case_size = [case_x, case_y, case_z];

// top of foot width
foot_x = (case_size[0]-usableDiv(maxDiv(case_size, finger))[0]*finger)/2;
foot_h = 8;
foot_ratio = .8;

/* component Locations */

// USB port location from center X 
usb_port_loc_x = -case_size[0]/2 + usb_port_x/2 + material + 8;
usb_port_loc_z = -case_size[2]/2 + usb_port_z/2 + material *2 + pico_z;
// patch the gap in the fingers under the USB port from the edge
usb_finger_patch_x = ceil(abs(usb_port_loc_x/2)/finger) * 5; 
// location of the patch starting with first negative cut
usb_finger_patch_loc_x = -(case_size[0]/2 - usb_finger_patch_x/2 - foot_x);

// pi pico location
pico_x_loc = -usb_port_loc_x;
pico_y_loc = case_size[1]/2 - 51.5/2 - material;
pico_z_loc = material/2 + 1 + material;
pico_rot = [0, 0, 90];
pico_plate = [pico_x, pico_y, material];

// speaker location
// speaker_loc_x = -1*(case_size[0]/2) + speaker_dim[1]/2 + material*2;
speaker_loc_x = -(case_size[0]/2 - cone_dia/2 - material*2);
speaker_loc_y = 0; // + speaker_dim[0]/2 + material*1.5 + ear_od;
speaker_loc_z = cone_height + material/2;
// speaker_loc_z =  speaker_dim[2]/2 + material/2;
// speaker_rot = [0, 0, 90];

speaker_rot = [180, 0, 0];


// realtime clock location
rtc_loc_x = case_size[0]/2 - rtc_x/2 - material*1.5;
rtc_loc_y = -1*(case_size[1]/2 - rtc_z/2 - material*2 +rtc_z/2 );
rtc_loc_z = rtc_y/2 + material;
rtc_rot = [90, 0, 180];
rtc_plate = [rtc_x+material/2, rtc_y+material/2, material];

// sd card reader location
sd_card_loc_x = -case_size[0]/2 + sd_x/2;
sd_card_loc_y = case_size[1]/2 - material * 2 - sd_z/2;
// sd_card_loc_z = material/2 + sd_y/2 + material;
// sd_card_loc_z = sd_y/2 + material*1.5;
sd_card_loc_z = case_size[2]/2 - sd_y/2 - material * 2;
sd_card_rot = [90, -0, 0];
sd_card_plate = [sd_x+material/2 - material, sd_y+material/2, material];

// MAX Amplifier location
max_x_loc = case_size[0]/2 - max_x/2 - 2*material;
max_y_loc = -pico_y_loc/2 - max_y/2;
max_z_loc = material *1.5 + max_z/2;
max_rot = [0, 0, 0];
max_plate = [max_x+material/2, max_y+material/2, material];

// plus and minus set button locations
pb_loc_x = -(case_size[0]/2 - material*2 - set_flange_d/2) +material;
pb_loc_y = case_size[1]/2;
pb_loc_z = case_size[2]/2 - material*2 -set_flange_d/2.5;
pb_rot = [-90, 0, 0];

// mb_loc_x = -(case_size[0]/2 - material*2 - set_flange_d*1.75);
mb_loc_x = pb_loc_x + set_flange_d*1.25;
mb_loc_y = pb_loc_y;
mb_loc_z = pb_loc_z;


// announcement button location
ann_loc_x = 0;
ann_loc_y = -case_size[1]/4;
ann_loc_z = case_size[2] - material/2;
ann_rot = [0, 0, 0];


// catch dimensions and locations
// length
catch_l = case_size[1] - material*3;

catch_loc_x = case_size[0]/2-material;
catch_loc_y = 0;
catch_loc_z = case_size[2]/2 - 2.5 * material;
catch_rot = [0, 0, -90];
catch_n_fingers = 3;
catch_n_fasteners = 2;
catch_fastener_d = 3;
catch_hole_d = 3.2;
catch_finger_clearance = 0;
catch_bolt_loc_x = catch_loc_x - (nut_plate_width(fastener_d=catch_fastener_d, clearance=.1))/2;

// epsilon to protect against div by zero
eps = 0.0001;

module multiline_text(lines, size=5, line_spacing=1.2, font="Helvetica") {
    color("white")
    for (i = [0 : len(lines) - 1]) {
        translate([0, -i * size * line_spacing]) {
            text(lines[i], size=size, halign="left", valign="baseline");
        }
    }
}
module mount_plate(dim=[5, 10, material], r=.5, color="red" ) {
    color(color) {
            chamfer_square(dim=dim, r=r, center=true);
        }
}


module usb_port(dim, r,) {
    module port_aperature() {
        union() {
            chamfer_square(dim=dim, r=r, center=true);
            translate([0, -(dim[1]/2 -r)]) {
                square([dim[0], r*2], center=true);
            }
        }
    }
    port_aperature();
}

// !usb_port([usb_port_x, usb_port_z], 1);

module foot(w=5, h=8, ratio=.8, center=false) {
    //make a single foot
    q = w - w*(1-ratio);

    trans_coord = center ? [-w/2, -h/2] : [0, 0, 0];
    
    coords = [[0, 0], [w, 0], 
              [q, h], [0, h]];
    translate(trans_coord) 
        polygon(coords);
    
}

module feet() {
    translate([-(case_size[0]/2-foot_x/2), -(case_size[2]/2+foot_h/2), 0]) 
        rotate([180, 0, 0])
        foot(foot_x, foot_h, foot_ratio, true);
    translate([(case_size[0]/2-foot_x/2), -(case_size[2]/2+foot_h/2), 0]) 
        rotate([180, 180, 0])
        foot(foot_x, foot_h, foot_ratio, true);
}


module base(print=false) {
    difference() {
        faceB(size=case_size, finger=finger, lidFinger=finger, material=material, 0);
        // translate([-usb_finger_patch_loc_x, -(case_size[1]/2-material/2)]) {
        //     square([usb_finger_patch_x, material], center=true);
        // }
        translate([speaker_loc_x, -speaker_loc_y]) {
            rotate([0, 0, 90])
            // cutter_square(x=speaker_dim[0], y=speaker_dim[1]);
            cutter_circle(d=cone_dia*.9);
        }
        if(print) {
            translate([-case_size[0]/2 + material*1.5, -case_size[1]/2 + 8 + material * 1.5]){
                multiline_text(["Talking Clock", "github.com/txoof/talking_clock"], size=4);
            }
        }
    }

 
}

module left() {
    sd_card_cutout = [sd_card_clearance, sd_y + material/2];
    difference() {
        faceC(size=case_size, finger=finger, lidFinger=finger, material=material);
        translate([-sd_card_loc_y + sd_z/2, -sd_card_loc_z]) {
            chamfer_square(dim=sd_card_cutout, r = .5, center=true);
        }

        translate([catch_loc_y, catch_loc_z]) {
            finger_slot_cutter(length=catch_l, material=material, finger_width=finger,
                            n_fingers=catch_n_fingers, slot_clearance=catch_finger_clearance);
        }        
    }
}

// !left();


 module right() {
    difference() {
        faceC(size=case_size, finger=finger, lidFinger=finger, material=material);
        translate([catch_loc_y, catch_loc_z]) {
            finger_slot_cutter(length=catch_l, material=material, finger_width=finger,
                            n_fingers=catch_n_fingers, slot_clearance=catch_finger_clearance);
        }
    }
 }
 
// !right();

 module front() {
    union() {
        difference() {
            faceA(size=case_size, finger=finger, lidFinger=finger, material=material);
        }
    feet();
    }
 }




 module back() {
    text_size = 10;
    valign = "center";
    halign = "center";
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

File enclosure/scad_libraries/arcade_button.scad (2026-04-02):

eps = 0.0001;

module arcade_button(body_z=29.5,
                    body_d=30,
                    button_z=3.5,
                    flange_z=3,
                    flange_d=33.3,
                    button_d=24,
                    contact_x=3,
                    contact_z=9.5,
                    $fn=36) {
  
  // body_z: total body height including plunger (excluding contact terminals)
  // body_d: body diameter - through-panel diameter
  // button_z: z-height over flange
  // button_z: z_height over panel
  // button_d: diameter of button
  // contact_x: width of contact
  // contact_z: depth of terminal below body

  displacement_z = -body_z+flange_z+button_z;
  lower_z = body_z-flange_z-button_z;

  color("Gold")
  union() {
    translate([0, 0, displacement_z]) {
      cylinder(body_z, d=button_d);
    }
    translate([0, 0, -lower_z]) {
      cylinder(h=lower_z, d=body_d);
    }
    cylinder(h=flange_z, d=flange_d);
    for (i = [-1, 1]) {
      translate([0, i*contact_x*1.5, displacement_z-contact_z+eps]) {
        cube([contact_x, .5, contact_z], center=false);
      }
    }
  }
  echo("Body Height:", body_z, "Total Height:", body_z+contact_z, "Internal Clearance:", body_z+contact_z-button_z-flange_z);
}

module arcade_button_cutter(body_d=30, $fn=128) {
  circle(d=body_d);
}

// arcadeSwitch();
// arcadeSwitchCutter();

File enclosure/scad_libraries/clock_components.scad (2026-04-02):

module dupont_pins(count=4, pin_pitch=2.54, pin_thick=0.64, pin_len=6) {
    y0 = -((count - 1) * pin_pitch) / 2;

    for (i = [0 : count - 1]) {
        translate([0, y0 + i * pin_pitch, 0]) {
            cube([pin_len + 4, pin_thick, pin_thick], center=true);
        }
    }
}

module max_amp(dim, terminal_h) {
    pin_thick = 0.64;
    pin_len = 6;
    color("mediumslateblue") {
        cube(dim, center=true);
    }
    
    terminal_block_dim = [pin_thick*5, dim[1]/2, terminal_h];

    color("blue") {
        translate([-dim[0]/2 + terminal_block_dim[0]/2, 0, terminal_h/2+dim[2]/2]) {

            cube(terminal_block_dim, center=true);
        }

    }

    color("gold") {
        translate([dim[0]/2 - 1, 0, pin_len/2 + dim[2]/2]) {
            rotate([0, 90, 0])
            dupont_pins(
                count=7,
                pin_thick=pin_thick,
                pin_len=pin_len
            );
        }
    }
    color("white") {
        translate([0, 0, dim[2] / 2]) {
            linear_extrude(height=0.4) {
                text("MAX", size=3, halign="center", valign="center");
            }
        }
    }    
}

module rtc(dim) {
    pin_thick = .64;
    pin_len = 6; 

    color("blue") {
        cube(dim, center=true);
    }
    
    color("gold") {
        translate([dim[0] / 2 + pin_len / 2, 0, dim[2] / 2 + pin_thick / 2]) {
            dupont_pins(
                count=4,
                pin_thick=pin_thick,
                pin_len=pin_len
            );
        }
    }

    color("white") {
        translate([0, 0, dim[2] / 2]) {
            linear_extrude(height=0.4) {
                text("RTC", size=3, halign="center", valign="center");
            }
        }
    }
}

module sd_card_reader(dim) {
    pin_thick = .64;
    pin_len = 6;     
    color("green") {
        cube(dim, center=true);
    }

    color("gold") {
        translate([dim[0] / 2 + pin_len / 2, 0, 1 + pin_thick / 2]) {
            dupont_pins(
                count=6,
                pin_thick=pin_thick,
                pin_len=pin_len
            );
        }
    }
    color("white") {
        translate([0, 0, dim[2] / 2]) {
            linear_extrude(height=0.4) {
                text("SD Card", size=3, halign="center", valign="center");
            }
        }
    }

}

module pi_pico() {
    // Pico X Dimensions
    pico_x = 51.5;
    // Pico Y Dimensions
    pico_y = 21;    

    pin_thick = .64;
    pin_len = 6; 

    color("darkseagreen") {
        cube([pico_x, pico_y, 2], center=true);
    }

    color("gold") {
        translate([0, pico_y/2 - pin_thick*1.5, pin_len]) {
            rotate([90, 90, 0])
            dupont_pins(
                count=20,
                pin_thick=pin_thick,
                pin_len=pin_len
            );
        }
        translate([0, -pico_y/2 + pin_thick*1.5, pin_len]) {
            rotate([90, 90, 0])
            dupont_pins(
                count=20,
                pin_thick=pin_thick,
                pin_len=pin_len
            );
        }

    }    

    color("white") {
        translate([0, 0, 2 / 2]) {
            linear_extrude(height=0.4) {
                text("Pi Pico", size=3, halign="center", valign="center");
            }
        }
    } 

}

module box_speaker(dim=[50, 45, 22], ears=true, od=8, h=4) {
    color("gray") {
        union() {
            for (i = [-1, 1]) {
                translate([i*(dim[0]/2+od/2), 0, 0]) {
                    union() {
                        translate([i*-od/2, 0, 0]) {
                            cube([od, od, h], center=true);
                        }
                        cylinder(d=od, center=true, h=h);
                    }
                }
            }
            cube(dim, center=true);
        }
    }
}

module dupont_bus_bar(dim=[35, 5, 2], col=9) {
    pin_thick=.64;
    pin_len = 6;
    color("orange") {
        cube(dim, center=true);
    }
    for (i=[-1, 1]) {
        translate([0, i*(dim[1]/2 - pin_thick), pin_len/2]) {
            rotate([0, 90, 90])
            dupont_pins(count=col);
        }
    }

    color("white") {
        translate([0, 0, 2 / 2]) {
            linear_extrude(height=0.4) {
                text("Bus Bar", size=3, halign="center", valign="center");
            }
        }
    } 

}

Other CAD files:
enclosure/scad_libraries/cone_speaker.scad
enclosure/scad_libraries/fasteners.scad
enclosure/scad_libraries/finger_joint_box.scad
enclosure/scad_libraries/speaker_grill.scad

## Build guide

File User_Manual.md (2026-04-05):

# Talking Clock User Manual

## Quick Start

**To get started:**

1. Plug the USB cable into the round port on the back of the clock, then connect it to a USB power adapter.
2. The clock will start up and announce the current time within a few seconds.
3. You may need to adjust the time.
4. Press the large button on top at any time to hear the time announced again.

That is all you need to know to use the clock. The rest of this manual describes how to adjust the volume, set the time, configure the alarm, and change other settings.

> **Note:** The time shown at startup comes from a small battery-powered clock inside the device. If the clock is new, or the internal battery was replaced, the time may need to be set. See *Setting the Time* below.

---

## Getting to Know Your Clock

The clock has three buttons.

**The Announce button** is the large round button on top of the clock. Press it at any time to hear the current time.

**The Plus button (+)** is a square button on the back of the clock, on the right side near the power cable. It is used to increase volume and navigate settings.

**The Minus button (-)** is a round button on the back of the clock. It is used to decrease volume and navigate settings.

The **USB power port** is on the back of the clock, next to the Plus button. Use any standard USB phone charger and cable. The clock does not have an on/off switch; it runs whenever it is plugged in.

There is a **SD card slot** on the left side of the clock. The SD card holds the clock's voice files and should be left in place during normal use.

The clock is made from laser-cut birch wood and is held together with four slotted bolts on the lid.

---

## Adjusting the Volume

With the clock in normal use, a short press of the Plus button raises the volume and a short press of the Minus button lowers it. Each press plays a brief tone so you can hear the change. There are 20 volume steps. The default is step 9. There is no spoken warning at the minimum or maximum; the tone simply stops changing in character.

Volume is saved automatically a few seconds after you stop adjusting it.

---

## Setting the Time

1. Hold either the Plus or Minus button for about 1.5 seconds. when you release the button, the clock says *"settings"*.
2. Press Plus or Minus briefly to scroll through the menu until you hear *"set time"*.
3. Press the Announce button to select it.
4. The clock will speak the current hour. Press Plus or Minus to change the hour. Each short press moves one hour and the clock speaks the new hour aloud.
5. When the hour is correct, press the Announce button to confirm it and move on to minutes.
6. The clock will speak the current minute. Press Plus or Minus to change the minute. Short presses move one minute at a time and are spoken aloud. Holding a button will step through minutes quickly with a beep for each step; when you release the button, the current minute or hour is spoken.
7. Press the Announce button to confirm and save the new time. The clock will announce the time you have set.

> **Tip:** If you stop interacting with the menu for about 30 seconds, the clock will say *"done"* and return to normal operation saving all the changes.

---

## The Settings Menu

Hold either the Plus or Minus button for about 1.5 seconds to open the settings menu. The clock will say *"settings"* and then announce the first item. Use short presses of Plus and Minus to move between items. Press the Announce button to select or change the current item. To exit the menu at any time, hold any button for 1.5 seconds; the clock will say *"done"*.

The menu items are:

- **Set time** - Set the current hour and minute.
- **Set alarm** - Set the alarm time. Uses the same hour and minute entry process as setting the time.
- **Alarm on/off** - Toggles the alarm between enabled and disabled.
- **Alarm tone** - Cycles through available alarm tones. The index number is announced, followed by a short preview of the tone played three times.
- **Announcement interval** - Sets the clock to announce the time automatically. Options are: off, every hour, every half hour, and every quarter hour. Off by default.
- **Time format** - Selects the speaking mode. See *Speaking Modes* below.
- **Voice** - Selects the voice and language. See *Voices and Languages* below.

---

## The Alarm

When the alarm is enabled and the set time is reached, the clock plays the selected tone three times, then announces the current time. It repeats this cycle every few seconds for up to five minutes. After five minutes, the alarm will be automatically silenced.

To silence the alarm, press the Announce button. The clock will announce the time and return to normal operation.

The alarm must be both set to the correct time and switched on to activate. Enabling the alarm is a separate step from setting the alarm time.

---

## Speaking Modes

The clock supports four modes for announcing the time. Each one reflects a different context and level of formality. You can change the mode in the settings menu under *"time format"*.

**Operational** is the style used in the military and aviation, where there is no ambiguity about AM or PM. Time is always expressed in 24-hour terms.

**Broadcast** is the style used in airports, train stations, and news programmes. AM or PM is always stated explicitly.

**Standard** is the default. It is the style used in offices and everyday professional settings. Practical and unambiguous without being overly formal.

**Casual** is conversational. It uses expressions like "quarter past" and "half past" in the way you might speak among friends.

| Time | Mode | Spoken |
|---|---|---|
| 8:30 AM | Operational | oh eight thirty |
| 8:45 PM | Operational | twenty forty-five |
| 9:27 AM | Broadcast | nine twenty-seven a.m. |
| 6:15 PM | Broadcast | six fifteen p.m. |
| 4:00 PM | Standard | four o'clock |
| 7:12 AM | Casual | quarter past seven |
| 9:28 PM | Casual | half past nine |

---

## Voices and Languages

The clock ships with several voice options in English and Dutch. Voices are selected in the settings menu under *"voice"*. When you cycle to a voice, the clock announces its name in that voice so you can hear how it sounds before confirming.

Additional voices and languages can be added to the SD card. The SD card is located on the left side of the clock. For instructions on creating and installing voice packages, refer to the project documentation.

---

## The Internal Battery

The clock contains a small battery that keeps the time accurate when the USB power is disconnected. This battery is separate from the USB power supply and is user-serviceable. If the clock loses track of the time when unplugged, the battery may need replacement. The battery is located inside the enclosure; the lid is held on by four slotted bolts.

---

## Reference: Button Summary

| Action | Button |
|---|---|
| Announce the time | Announce (top, large button)  |
| Raise volume | Plus - short press |
| Lower volume | Minus - short press |
| Open settings menu | Hold Plus or Minus (1.5 sec)  |
| Scroll through menu | Plus or Minus - short press |
| Select menu item | Announce - short press |
| Exit menu | Hold any button (1.5 sec) |
| Silence alarm | Announce |

---

## Reference: Menu Item Summary

| Menu Item | What it does |
|---|---|
| Set time | Set the current hour and minute |
| Set alarm | Set the hour and minute for the alarm |
| Alarm on/off | Enable or disable the alarm |
| Alarm tone | Choose from available alarm tones |
| Announcement interval | Auto-announce off / hourly / half-hourly / quarterly |
| Time format | Select speaking mode (operational/broadcast/standard/casual) |
| Voice | Select voice and language |

---

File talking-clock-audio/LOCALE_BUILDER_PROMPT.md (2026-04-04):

# Talking Clock Locale Builder Prompt

This document contains a system prompt for use with an LLM (ChatGPT, Claude, Llama, or similar) to help you build a valid `time_phrases_LOCALE.yaml` file for the Talking Clock project.

## How to use this prompt

The prompt below is a **system prompt**. Setting it as a system prompt (rather than pasting it as a regular message) gives the LLM persistent instructions for the entire conversation. This produces significantly better results.

**ChatGPT:**

1. Start a new conversation.
2. Click the model name at the top and select "Custom instructions", or use the
   GPT builder to set a system prompt.
3. Paste the prompt below into the system instructions field.
4. Start the conversation by telling the LLM which language you are building.

**Claude (claude.ai):**

1. Create a new Project.
2. In the Project settings, paste the prompt below into the "Custom instructions"
   field.
3. Start a conversation in that project by telling Claude which language you are
   building.

**Local LLMs (Ollama, LM Studio, etc.):**

1. Use the system prompt field in your interface, or prefix your first message
   with `<system>...</system>` tags containing the prompt below.

---

## System Prompt

Paste everything between the dashed lines below as your system prompt.

---

You are a specialist assistant helping a user build a `time_phrases_LOCALE.yaml`
configuration file for the Talking Clock project. This file defines how a
talking clock announces the time in a specific language using pre-recorded TTS
audio clips.

Your goal is to produce a complete, valid YAML file that correctly captures how
native speakers of the target language naturally express the time. You will do
this through a structured conversation before producing any YAML output.

## Your approach

Work through the following steps in order. Do not skip ahead or produce YAML
until you have completed all steps.

### Step 1: Identify the language and locale

Ask the user:
- Which language are they building for?
- What is the locale code? (e.g. de_DE for German, fr_FR for French, ja_JP for
  Japanese)
- Are there regional variations to be aware of?

### Step 2: Collect vocabulary

Ask the user to provide translations for the following words. Explain that these
are the only spoken words the clock will use, so naturalness matters more than
literal translation. Ask for each group separately to avoid overwhelming the
user:

Group A - time words:
- o'clock (or equivalent on-the-hour marker)
- past / after (used in "ten past three") -- note if not used in this language
- to / before (used in "ten to four") -- note if not used in this language
- quarter
- half
- the word spoken before a single-digit minute (e.g. "oh" in "oh nine")
- zero (numeric)
- hundred (used in "fourteen hundred hours")
- hours (used in "fourteen hundred hours")
- midnight
- noon
- almost / nearly (used in "almost nine")

Group B - AM/PM:
- Does this language use AM/PM suffixes when telling time?
- If yes, what are the spoken forms?

Group C - numbers 0 through 59:
- Ask the user to confirm the spoken forms of numbers 0-59, noting any that
  differ from simple cardinal numbers (e.g. in some languages the spoken form
  of "1" when telling time differs from the usual word for "one").

### Step 3: Understand time-telling conventions per mode

The clock supports four announcement modes. For each mode, ask the user to
describe or give examples of how a native speaker would say specific times.
Use these probe times for each mode:

- 00:00 (midnight)
- 12:00 (noon)
- 08:00 (on the hour, morning)
- 08:09 (single-digit minute, morning)
- 08:15 (quarter past)
- 08:30 (half hour)
- 08:45 (quarter to)
- 08:55 (near the hour)
- 14:30 (afternoon, 24-hour context)
- 20:48 (evening)

**Operational mode** - precise 24-hour format, used in formal or assistive
contexts. Example in English: "fourteen thirty hours", "zero nine hundred hours".

**Broadcast mode** - 12-hour format with AM/PM, as used in radio or news.
Example in English: "two thirty p m", "eight oh nine a m".

**Standard mode** - 12-hour format without AM/PM. Clean and unambiguous.
Example in English: "two thirty", "eight oh nine".

**Casual mode** - conversational phrasing as a native speaker would naturally
say it. This is the most language-specific mode. Examples in English: "half
past two", "quarter to nine", "almost nine". Examples in Dutch: "half drie"
(half three, meaning 2:30), "kwart voor negen" (quarter to nine).

Pay particular attention to casual mode. Ask the user:
- How do they say times on the hour? (e.g. "three o'clock", "drei Uhr")
- How do they say times just past the hour? (e.g. "five past three")
- How do they say the quarter hour? (e.g. "quarter past three")
- How do they say the half hour? (e.g. "half past three" in English vs "half
  four" meaning 3:30 in Dutch and German -- this is a common source of errors)
- How do they say times approaching the next hour? (e.g. "ten to four")
- How do they say times very close to the next hour? (e.g. "almost four")
- Are there any special cases beyond midnight and noon?

### Step 4: Determine the casual mode minute boundaries

Based on the conventions the user described, propose a mapping of minute ranges
to patterns for casual mode. For example:

- Minutes 0-2: on the hour
- Minutes 3-7: minutes past
- Minutes 8-17: quarter past
- Minutes 18-21: minutes past
- Minutes 22-37: half past (or half next hour, depending on language)
- Minutes 38-42: minutes to
- Minutes 43-49: quarter to
- Minutes 50-54: minutes to
- Minutes 55-59: almost

Ask the user to confirm or adjust these boundaries before proceeding. Make sure
to flag languages where "half" refers to the upcoming hour rather than the past
hour (e.g. Dutch "half drie" = 2:30, not 3:30).

### Step 5: Collect and verify examples

Before generating the YAML, ask the user to confirm the expected spoken output
for the following times in each mode. These will become the `examples:` block,
which the `tca validate` command uses as a test suite.

Required examples (collect spoken phrase for each mode):
- 00:00
- 12:00
- 08:00
- 14:30
- 20:48

Ask the user to write out the exact words as they should be spoken, with words
separated by spaces. Explain that these must exactly match what the rules will
produce, and that `tca validate` will flag any mismatch.

### Step 6: Generate the YAML

Only after completing steps 1-5, produce the complete YAML file.

Use the following template structure exactly. Do not add keys that are not in
the template. Do not remove required keys. Fill in all TRANSLATE placeholders
with the values collected in the conversation.

For the casual mode, use the minute_map schema with special_cases for midnight
and noon. Assign every minute 0-59 to a pattern name. Do not leave any minute
unassigned.

After producing the YAML, explain briefly:
- Any assumptions you made about the language's time-telling conventions
- Any places where you were uncertain and the user should double-check
- How to run `tca validate --yaml time_phrases_LOCALE.yaml` to check the output

## YAML template to fill in

```yaml
locale: LOCALE

description: >
  LANGUAGE_NAME time phrases.
  Source YAML for compiling locale-specific Pico rule files.

vocab:
  words:
    oclock: "TRANSLATE"
    past: "TRANSLATE"
    to: "TRANSLATE"
    quarter: "TRANSLATE"
    half: "TRANSLATE"
    oh: "TRANSLATE"
    zero: "TRANSLATE"
    hundred: "TRANSLATE"
    hours: "TRANSLATE"
    midnight: "TRANSLATE"
    noon: "TRANSLATE"
    almost: "TRANSLATE"

  menu:
    enter: "TRANSLATE"
    exit: "TRANSLATE"
    set_time: "TRANSLATE"
    set_alarm: "TRANSLATE"
    alarm_enabled: "TRANSLATE"
    alarm_tone: "TRANSLATE"
    voice: "TRANSLATE"
    announce_interval: "TRANSLATE"
    mode: "TRANSLATE"

  toggle:
    on: "TRANSLATE"
    off: "TRANSLATE"

  interval:
    hourly: "TRANSLATE"
    half: "TRANSLATE"
    quarter: "TRANSLATE"

  voice:
    name: "TRANSLATE"

  mode:
    operational: "TRANSLATE"
    broadcast: "TRANSLATE"
    standard: "TRANSLATE"
    casual: "TRANSLATE"

  number_words:
    0: "TRANSLATE"
    1: "TRANSLATE"
    2: "TRANSLATE"
    3: "TRANSLATE"
    4: "TRANSLATE"
    5: "TRANSLATE"
    6: "TRANSLATE"
    7: "TRANSLATE"
    8: "TRANSLATE"
    9: "TRANSLATE"
    10: "TRANSLATE"
    11: "TRANSLATE"
    12: "TRANSLATE"
    13: "TRANSLATE"
    14: "TRANSLATE"
    15: "TRANSLATE"
    16: "TRANSLATE"
    17: "TRANSLATE"
    18: "TRANSLATE"
    19: "TRANSLATE"
    20: "TRANSLATE"
    21: "TRANSLATE"
    22: "TRANSLATE"
    23: "TRANSLATE"
    24: "TRANSLATE"
    25: "TRANSLATE"
    26: "TRANSLATE"
    27: "TRANSLATE"
    28: "TRANSLATE"
    29: "TRANSLATE"
    30: "TRANSLATE"
    31: "TRANSLATE"
    32: "TRANSLATE"
    33: "TRANSLATE"
    34: "TRANSLATE"
    35: "TRANSLATE"
    36: "TRANSLATE"
    37: "TRANSLATE"
    38: "TRANSLATE"
    39: "TRANSLATE"
    40: "TRANSLATE"
    41: "TRANSLATE"
    42: "TRANSLATE"
    43: "TRANSLATE"
    44: "TRANSLATE"
    45: "TRANSLATE"
    46: "TRANSLATE"
    47: "TRANSLATE"
    48: "TRANSLATE"
    49: "TRANSLATE"
    50: "TRANSLATE"
    51: "TRANSLATE"
    52: "TRANSLATE"
    53: "TRANSLATE"
    54: "TRANSLATE"
    55: "TRANSLATE"
    56: "TRANSLATE"
    57: "TRANSLATE"
    58: "TRANSLATE"
    59: "TRANSLATE"

fields:
  computed:
    h12: "((hour_24 + 11) % 12) + 1"
    next_h12: "(h12 % 12) + 1"
    m_to: "60 - minute"
    day_period:
      when_hour_24_lt_12: "am"
      otherwise: "pm"

modes:
  operational:
    patterns:
      midnight: ["words.midnight"]
      noon: ["words.noon"]
      hundred_hours: ["number_words.{h24}", "words.hundred", "words.hours"]
      zero_pad: ["number_words.{h24}", "words.zero", "number_words.{m}", "words.hours"]
      full: ["number_words.{h24}", "number_words.{m}", "words.hours"]
    rules:
      - when: {hour_24_eq: 0, minute_eq: 0}
        pattern: midnight
      - when: {hour_24_eq: 12, minute_eq: 0}
        pattern: noon
      - when: {minute_eq: 0}
        pattern: hundred_hours
      - when: {minute_gt: 0, minute_lt: 10}
        pattern: zero_pad
      - when: {any: true}
        pattern: full

  broadcast:
    patterns:
      midnight: ["words.midnight"]
      noon: ["words.noon"]
      oclock: ["number_words.{h12}", "words.oclock", "words.{period}"]
      zero_pad: ["number_words.{h12}", "words.oh", "number_words.{m}", "words.{period}"]
      full: ["number_words.{h12}", "number_words.{m}", "words.{period}"]
    rules:
      - when: {hour_24_eq: 0, minute_eq: 0}
        pattern: midnight
      - when: {hour_24_eq: 12, minute_eq: 0}
        pattern: noon
      - when: {minute_eq: 0}
        pattern: oclock
      - when: {minute_gt: 0, minute_lt: 10}
        pattern: zero_pad
      - when: {any: true}
        pattern: full

  standard:
    patterns:
      midnight: ["words.midnight"]
      noon: ["words.noon"]
      oclock: ["number_words.{h12}", "words.oclock"]
      zero_pad: ["number_words.{h12}", "words.oh", "number_words.{m}"]
      full: ["number_words.{h12}", "number_words.{m}"]
    rules:
      - when: {hour_24_eq: 0, minute_eq: 0}
        pattern: midnight
      - when: {hour_24_eq: 12, minute_eq: 0}
        pattern: noon
      - when: {minute_eq: 0}
        pattern: oclock
      - when: {minute_gt: 0, minute_lt: 10}
        pattern: zero_pad
      - when: {any: true}
        pattern: full

  casual:
    patterns:
      midnight: ["words.midnight"]
      noon: ["words.noon"]
      oclock: ["number_words.{h12}", "words.oclock"]
      # ADD PATTERNS FOR YOUR LANGUAGE HERE
    special_cases:
      "00:00": midnight
      "12:00": noon
    minute_map:
      0: oclock
      # FILL IN ALL MINUTES 1-59

examples:
  "00:00":
    operational: "EXPECTED PHRASE"
    broadcast: "EXPECTED PHRASE"
    standard: "EXPECTED PHRASE"
    casual: "EXPECTED PHRASE"
  "12:00":
    operational: "EXPECTED PHRASE"
    broadcast: "EXPECTED PHRASE"
    standard: "EXPECTED PHRASE"
    casual: "EXPECTED PHRASE"
  "08:00":
    operational: "EXPECTED PHRASE"
    broadcast: "EXPECTED PHRASE"
    standard: "EXPECTED PHRASE"
    casual: "EXPECTED PHRASE"
  "14:30":
    operational: "EXPECTED PHRASE"
    broadcast: "EXPECTED PHRASE"
    standard: "EXPECTED PHRASE"
    casual: "EXPECTED PHRASE"
  "20:48":
    operational: "EXPECTED PHRASE"
    broadcast: "EXPECTED PHRASE"
    standard: "EXPECTED PHRASE"
    casual: "EXPECTED PHRASE"
```

## Rules for valid YAML output

- Every minute 0-59 must appear in the minute_map. Missing minutes will cause
  a runtime error on the clock.
- Every pattern referenced in minute_map or special_cases must be defined in
  patterns.
- Every token in a pattern must either be a known words.KEY or number_words.KEY
  entry, or use a valid placeholder like {h12}, {m}, {next_h12}, {m_to},
  {period}.
- The examples block must use the exact spoken words separated by spaces, not
  the token keys.
- Do not add extra vocab keys beyond those in the template unless they are
  genuinely needed for new patterns.

---

*End of system prompt.*

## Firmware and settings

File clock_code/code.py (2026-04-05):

import time
time.sleep(1)
print("clock start up")

import board
import busio
import digitalio
import storage
import sdcardio
import audiobusio
import audiocore
import audiomixer
import keypad
import json
import os

import adafruit_ds3231

from voices import scan_voices, resolve_token, load_rules, scan_alarm_tones
from menu import Menu
from debug_mode import check_debug_boot, run_debug_mode
import pico_rules


VERSION = "0.4.1"


# --- Debug boot check (must run before keypad.Keys takes GP6) ---

_debug_boot = check_debug_boot()

# --- Hardware init ---

spi = busio.SPI(clock=board.GP18, MOSI=board.GP19, MISO=board.GP16)
sdcard = sdcardio.SDCard(spi, board.GP17)
vfs = storage.VfsFat(sdcard)
storage.mount(vfs, "/sd")
print("SD card mounted")

i2c = busio.I2C(scl=board.GP1, sda=board.GP0)
rtc = adafruit_ds3231.DS3231(i2c)

gain = digitalio.DigitalInOut(board.GP13)
gain.direction = digitalio.Direction.OUTPUT
gain.value = True

sd = digitalio.DigitalInOut(board.GP9)
sd.direction = digitalio.Direction.OUTPUT
sd.value = True

ANNOUNCE = 0
PLUS     = 1
MINUS    = 2

if not _debug_boot:
    keys = keypad.Keys(
        (board.GP6, board.GP7, board.GP8),
        value_when_pressed=False,
        pull=True,
    )

audio = audiobusio.I2SOut(bit_clock=board.GP11, word_select=board.GP12, data=board.GP10)
mixer = audiomixer.Mixer(voice_count=1, sample_rate=22050, channel_count=1,
                         bits_per_sample=16, samples_signed=True, buffer_size=2048)
audio.play(mixer)

# --- Enter debug mode if ANNOUNCE was held at boot ---

if _debug_boot:
    print("Debug mode requested - handing off")
    run_debug_mode(mixer)
    # run_debug_mode never returns; reboot to exit
    while True:
        pass

# --- Config ---

CONFIG_PATH    = "/sd/config.json"
MENU_PATH      = "/menu.json"
VOLUME_STEPS   = 20
VOLUME_DELAY   = 5.5
HOLD_SECONDS   = 1.5
VALUE_REPEAT_INTERVAL = 0.150  # seconds between increments when held
ALARM_MAX_SECS = 300  # 5 minutes

DEFAULT_CONFIG = {
    "volume_step":       9,
    "voice":             "en_US_lessac_medium",
    "mode":              "standard",
    "alarm_enabled":     False,
    "alarm_hour":        7,
    "alarm_minute":      0,
    "alarm_tone":        "/sd/audio_assets/volume_boop.wav",
    "announce_interval": "off",
}

def load_config():
    try:
        with open(CONFIG_PATH, "r") as f:
            data = json.load(f)
        for k, v in DEFAULT_CONFIG.items():
            if k not in data:
                data[k] = v
        data["volume_step"] = max(1, data.get("volume_step", DEFAULT_CONFIG["volume_step"]))
        return data
    except Exception:
        return dict(DEFAULT_CONFIG)

def save_config(cfg):
    try:
        with open(CONFIG_PATH, "w") as f:
            json.dump(cfg, f)
        print("Config saved")
    except Exception as e:
        print("Config save failed:", e)

config = load_config()
save_config(config)

# --- Voice / vocab / rules ---

voices = scan_voices()
alarm_tones = scan_alarm_tones()
print(f"Alarm tones: {[t['filename'] for t in alarm_tones]}")

def load_voice(name):
    if name not in voices:
        name = list(voices.keys())[0]
        print(f"Requested voice not found, using {name}")
    return name, voices[name]

active_voice_name, active_voice = load_voice(config["voice"])
print(f"Voice: {active_voice_name}")

def reload_rules():
    global active_rules
    active_rules = load_rules(active_voice, config["mode"])
    if active_rules:
        print(f"Rules loaded: {config['mode']}")
    else:
        print(f"Rules load failed for mode: {config['mode']}")

active_rules = None
reload_rules()

# --- Startup diagnostics ---
if active_voice:
    print(f"Vocab: {len(active_voice['vocab'])} keys")
if active_rules:
    print(f"Rules: {list(active_rules.get('modes', {}).keys())}")
else:
    print("Rules: failed to load")

volume_step        = config.get("volume_step", 7)
mixer.voice[0].level = volume_step / VOLUME_STEPS
volume_dirty_since = None

# --- Audio ---

BOOP_PATH = "/sd/audio_assets/volume_boop.wav"
BEEP_PATH = "/sd/audio_assets/beep.wav"

def play_path(path):
    try:
        with open(path, "rb") as f:
            wav = audiocore.WaveFile(f)
            mixer.voice[0].play(wav)
            while mixer.voice[0].playing:
                pass
    except Exception as e:
        print(f"play_path failed {path}: {e}")

def stop_audio():
    mixer.voice[0].stop()

def play_token(token):
    path = resolve_token(active_voice, token)
    play_path(path)

def play_token_for_voice(voice_entry, token):
    """Resolve and play a token through a specific voice, not the active one."""
    path = resolve_token(voice_entry, token)
    play_path(path)

def play_boop():
    play_path(BOOP_PATH)

def discard_events():
    while keys.events.get() is not None:
        pass

def play_sequence(hour_24, minute):
    """Play a time announcement using active rules, interruptible by PLUS or MINUS."""
    vocab = active_voice["vocab"]

    if active_rules:
        files = pico_rules.get_audio_files(active_rules, vocab, config["mode"], hour_24, minute)
        if files:
            files = [f"{active_voice['path']}/audio/{f}" for f in files]
        else:
            print(f"No rule match for {hour_24:02d}:{minute:02d} in mode {config['mode']}")
            return
    else:
        print("No rules loaded, cannot announce")
        return

    print(f"{hour_24:02d}:{minute:02d} [{config['mode']}] -> {files}")

    handles = []
    wavs    = []
    try:
        for path in files:
            fh = open(path, "rb")
            handles.append(fh)
            wavs.append(audiocore.WaveFile(fh))
        for wav in wavs:
            mixer.voice[0].play(wav)
            while mixer.voice[0].playing:
                ev = keys.events.get()
                if ev and ev.pressed and ev.key_number in (PLUS, MINUS):
                    stop_audio()
                    discard_events()
                    return
    finally:
        for fh in handles:
            fh.close()
        discard_events()

# --- Menu ---

def load_menu_items():
    with open(MENU_PATH, "r") as f:
        data = json.load(f)
    items = data["items"]

    for item in items:
        if item["id"] == "voice":
            item["options"] = [
                {"value": name, "audio_token": "voice.name", "voice": name}
                for name in voices.keys()
            ]
        elif item["id"] == "mode":
            item["options"] = [
                {"value": m, "audio_token": f"mode.{m}"}
                for m in active_voice.get("modes", [])
            ]
        elif item["id"] == "alarm_tone":
            item["options"] = [
                {"value": t["path"], "audio_token": None, "index": t["index"], "path": t["path"]}
                for t in alarm_tones
            ]
    return items

def on_action(action):
    global mode, set_hour, set_minute, active_voice_name, active_voice, last_interaction, value_repeat_key, value_repeat_next, value_did_repeat

    if action == "set_time":
        h, m = now()
        set_hour          = h
        set_minute        = m
        mode              = "set_hour"
        last_interaction  = time.monotonic()
        value_repeat_key  = None
        value_repeat_next = None
        value_did_repeat  = False
        play_token("menu.set_time")
        play_sequence_hour(set_hour)

    elif action == "set_alarm":
        set_hour          = config["alarm_hour"]
        set_minute        = config["alarm_minute"]
        mode              = "set_alarm_hour"
        last_interaction  = time.monotonic()
        value_repeat_key  = None
        value_repeat_next = None
        value_did_repeat  = False
        play_token("menu.set_alarm")
        play_sequence_hour_alarm(set_hour)

    elif action == "reload_voice":
        name = config["voice"]
        active_voice_name, active_voice = load_voice(name)
        print(f"Voice reloaded: {active_voice_name}")
        reload_rules()
        play_token("menu.enter")

    elif action == "reload_mode":
        reload_rules()
        play_token(f"mode.{config['mode']}")
        h, m = now()
        play_sequence(h, m)

menu = Menu(
    items                = load_menu_items(),
    config               = config,
    save_config          = save_config,
    play_token           = play_token,
    on_action            = on_action,
    play_token_for_voice = play_token_for_voice,
    voices               = voices,
    play_path            = play_path,
)

# --- Time setting helpers ---

def play_sequence_hour(h):
    play_sequence(h, 0)

def play_sequence_hour_alarm(h):
    # Play hour for alarm setting - always appends day period word for clarity.
    play_sequence(h, 0)
    if active_rules:
        day_period_table = active_rules.get("day_period", [])
        period = pico_rules._resolve_period(day_period_table, h)
        if period:
            path = resolve_token(active_voice, f"words.{period}")
            play_path(path)

def play_sequence_minute(m):
    path = resolve_token(active_voice, f"number_words.{m}")
    play_path(path)

# --- Alarm ---

ALARM_TONE_REPEATS = 3
ALARM_CYCLE_PAUSE  = 3.0  # seconds between cycles

alarm_ringing    = False
alarm_start      = None
alarm_next_cycle = None

def _alarm_tone_path():
    return config.get("alarm_tone", "/sd/audio_assets/volume_boop.wav")

def check_alarm():
    global alarm_ringing, alarm_start, alarm_next_cycle
    if not config.get("alarm_enabled"):
        return
    t = rtc.datetime
    if t.tm_hour == config["alarm_hour"] and t.tm_min == config["alarm_minute"] and t.tm_sec < 2:
        if not alarm_ringing:
            alarm_ringing    = True
            alarm_start      = time.monotonic()
            alarm_next_cycle = alarm_start
            print("Alarm triggered")

def tick_alarm():
    global alarm_ringing, alarm_next_cycle
    if not alarm_ringing:
        return
    now_t = time.monotonic()
    if (now_t - alarm_start) >= ALARM_MAX_SECS:
        alarm_ringing = False
        print("Alarm timed out")
        return
    if now_t >= alarm_next_cycle:
        tone_path = _alarm_tone_path()
        for _ in range(ALARM_TONE_REPEATS):
            play_path(tone_path)
            if not alarm_ringing:
                return
        h, m = now()
        play_sequence(h, m)
        alarm_next_cycle = time.monotonic() + ALARM_CYCLE_PAUSE

def silence_alarm():
    global alarm_ringing
    alarm_ringing = False
    print("Alarm silenced")
    h, m = now()
    play_sequence(h, m)

# --- Auto-announce ---

last_announced_minute = -1

def check_auto_announce():
    global last_announced_minute
    interval = config.get("announce_interval", "off")
    if interval == "off":
        return
    t = rtc.datetime
    h = t.tm_hour
    m = t.tm_min
    if m == last_announced_minute:
        return
    announce = False
    if interval == "hourly" and m == 0:
        announce = True
    elif interval == "half" and m in (0, 30):
        announce = True
    elif interval == "quarter" and m in (0, 15, 30, 45):
        announce = True
    if announce:
        last_announced_minute = m
        play_sequence(h, m)

# --- State ---

mode             = "normal"
set_hour         = 0
set_minute       = 0
held             = {PLUS: None, MINUS: None, ANNOUNCE: None}
last_interaction = None
VALUE_ENTRY_TIMEOUT = 30.0

value_repeat_key  = None
value_repeat_next = None
value_did_repeat  = False

def now():
    t = rtc.datetime
    return t.tm_hour, t.tm_min

def print_status():
    print(f"Version: {VERSION}")
    print(f"Config: {config}")
    print(f"Voice: {active_voice_name}  Mode: {config['mode']}")

print_status()
h, m = now()
print(f"RTC time: {h:02d}:{m:02d}")

if len(alarm_tones) > 1:
    play_path(alarm_tones[1]["path"])
h, m = now()
# play_sequence(h, m)
print("Boot completed - starting operation")
# --- Main loop ---

while True:
    now_t = time.monotonic()
    event = keys.events.get()

    if event:
        key = event.key_number

        if event.pressed:
            held[key] = now_t

        # --- Alarm silencing takes priority ---
        if alarm_ringing and event.pressed and key == ANNOUNCE:
            held[key] = None
            silence_alarm()
            continue

        # --- Menu active: forward all events ---
        if menu.active:
            if event.released:
                duration = (now_t - held[key]) if held[key] is not None else 0
                held[key] = None
                press_type = "long" if duration >= HOLD_SECONDS else "short"
                print(f"Menu: key={key} duration={duration:.2f}s type={press_type}")
                menu.handle_event(key, press_type)
            continue

        # --- Normal mode ---
        if mode == "normal":
            if key in (PLUS, MINUS):
                if event.released:
                    press_time = held.get(key)
                    held[key] = None
                    duration = (now_t - press_time) if press_time is not None else 0
                    if duration < HOLD_SECONDS:
                        if key == PLUS:
                            volume_step = min(VOLUME_STEPS, volume_step + 1)
                        else:
                            volume_step = max(1, volume_step - 1)
                        mixer.voice[0].level = volume_step / VOLUME_STEPS
                        print(f"Volume: {volume_step}/{VOLUME_STEPS}")
                        play_boop()
                        volume_dirty_since = now_t

            if event.pressed and key == ANNOUNCE:
                h, m = now()
                play_sequence(h, m)

            if event.released and key == ANNOUNCE:
                held[key] = None

        # --- Set time: hour ---
        elif mode == "set_hour":
            if event.pressed and key in (PLUS, MINUS):
                last_interaction    = now_t
                value_repeat_key    = key
                value_repeat_next   = now_t + HOLD_SECONDS
                value_did_repeat    = False
            elif event.released and key in (PLUS, MINUS):
                value_repeat_key  = None
                value_repeat_next = None
                last_interaction  = now_t
                if not value_did_repeat:
                    set_hour = (set_hour + 1) % 24 if key == PLUS else (set_hour - 1) % 24
                play_sequence_hour(set_hour)
                value_did_repeat = False
            elif event.pressed and key == ANNOUNCE:
                value_repeat_key = None
                last_interaction = now_t
                mode = "set_minute"
                play_sequence_minute(set_minute)

        # --- Set time: minute ---
        elif mode == "set_minute":
            if event.pressed and key in (PLUS, MINUS):
                last_interaction    = now_t
                value_repeat_key    = key
                value_repeat_next   = now_t + HOLD_SECONDS
                value_did_repeat    = False
            elif event.released and key in (PLUS, MINUS):
                value_repeat_key  = None
                value_repeat_next = None
                last_interaction  = now_t
                if not value_did_repeat:
                    set_minute = (set_minute + 1) % 60 if key == PLUS else (set_minute - 1) % 60
                play_sequence_minute(set_minute)
                value_did_repeat = False
            elif event.pressed and key == ANNOUNCE:
                value_repeat_key = None
                last_interaction = now_t
                t = rtc.datetime
                rtc.datetime = time.struct_time((
                    t.tm_year, t.tm_mon, t.tm_mday,
                    set_hour, set_minute, 0,
                    t.tm_wday, t.tm_yday, t.tm_isdst
                ))
                mode = "normal"
                play_sequence(set_hour, set_minute)

        # --- Set alarm: hour ---
        elif mode == "set_alarm_hour":
            if event.pressed and key in (PLUS, MINUS):
                last_interaction    = now_t
                value_repeat_key    = key
                value_repeat_next   = now_t + HOLD_SECONDS
                value_did_repeat    = False
            elif event.released and key in (PLUS, MINUS):
                value_repeat_key  = None
                value_repeat_next = None
                last_interaction  = now_t
                if not value_did_repeat:
                    set_hour = (set_hour + 1) % 24 if key == PLUS else (set_hour - 1) % 24
                play_sequence_hour_alarm(set_hour)
                value_did_repeat = False
            elif event.pressed and key == ANNOUNCE:
                value_repeat_key = None
                last_interaction = now_t
                mode = "set_alarm_minute"
                play_sequence_minute(set_minute)

        # --- Set alarm: minute ---
        elif mode == "set_alarm_minute":
            if event.pressed and key in (PLUS, MINUS):
                last_interaction    = now_t
                value_repeat_key    = key
                value_repeat_next   = now_t + HOLD_SECONDS
                value_did_repeat    = False
            elif event.released and key in (PLUS, MINUS):
                value_repeat_key  = None
                value_repeat_next = None
                last_interaction  = now_t
                if not value_did_repeat:
                    set_minute = (set_minute + 1) % 60 if key == PLUS else (set_minute - 1) % 60
                play_sequence_minute(set_minute)
                value_did_repeat = False
            elif event.pressed and key == ANNOUNCE:
                value_repeat_key = None
                last_interaction = now_t
                config["alarm_hour"]   = set_hour
                config["alarm_minute"] = set_minute
                save_config(config)
                mode = "normal"
                play_sequence(set_hour, set_minute)

    # --- Long press PLUS/MINUS in normal mode: enter menu ---
    if mode == "normal" and not menu.active:
        for key in (PLUS, MINUS):
            if held[key] is not None and (now_t - held[key]) >= HOLD_SECONDS:
                duration = now_t - held[key]
                print(f"Menu: long-press detected key={key} duration={duration:.2f}s")
                print_status()
                held[PLUS] = None
                held[MINUS] = None
                held[ANNOUNCE] = None
                menu.enter()
                discard_events()
                break

    # --- Value-entry inactivity timeout ---
    if mode in ("set_hour", "set_minute", "set_alarm_hour", "set_alarm_minute"):
        if last_interaction is not None and (now_t - last_interaction) >= VALUE_ENTRY_TIMEOUT:
            print(f"Value entry: inactivity timeout in mode '{mode}'")
            mode = "normal"
            last_interaction = None
            play_token("menu.exit")

    # --- Value-entry hold repeat ---
    if value_repeat_key is not None and mode in ("set_hour", "set_minute", "set_alarm_hour", "set_alarm_minute"):
        if now_t >= value_repeat_next:
            value_did_repeat   = True
            value_repeat_next  = now_t + VALUE_REPEAT_INTERVAL
            last_interaction   = now_t
            if value_repeat_key == PLUS:
                if mode in ("set_hour", "set_alarm_hour"):
                    set_hour = (set_hour + 1) % 24
                else:
                    set_minute = (set_minute + 1) % 60
            else:
                if mode in ("set_hour", "set_alarm_hour"):
                    set_hour = (set_hour - 1) % 24
                else:
                    set_minute = (set_minute - 1) % 60
            play_path(BEEP_PATH)

    # --- Menu inactivity timeout ---
    menu.tick()

    # --- Deferred volume save ---
    if volume_dirty_since is not None:
        if (now_t - volume_dirty_since) >= VOLUME_DELAY:
            config["volume_step"] = volume_step
            save_config(config)
            volume_dirty_since = None

    # --- Auto-announce and alarm ---
    if mode == "normal" and not menu.active and not alarm_ringing:
        check_auto_announce()
        check_alarm()

    if alarm_ringing:
        tick_alarm()

    time.sleep(0.02)

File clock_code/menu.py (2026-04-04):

# menu.py
#
# Audio-only settings menu state machine.
#
# This module is event-driven. The main loop calls handle_event() with each
# button event and calls tick() on every iteration for timeout checking.
# It never blocks and never reads buttons directly.
#
# Button constants match code.py:
#   ANNOUNCE = 0, PLUS = 1, MINUS = 2
#
# Callers must supply two callables at construction:
#   play_token(token)         - plays a token through the active voice
#   play_token_for_voice(voice_entry, token)
#                             - plays a token through a specific voice entry
#   on_action(action)         - called when an action item is confirmed

import time

ANNOUNCE = 0
PLUS     = 1
MINUS    = 2

STATE_IDLE = "idle"
STATE_MENU = "menu"

INACTIVITY_TIMEOUT = 30.0


class Menu:
    def __init__(self, items, config, save_config, play_token, on_action,
                 play_token_for_voice=None, voices=None, play_path=None):
        """Initialise the menu.

        Args:
            items:                list of item dicts from menu.json.
            config:               the live config dict (mutated directly on toggle).
            save_config:          callable(config) - persists config to SD.
            play_token:           callable(token) - plays token in active voice.
            on_action:            callable(action) - fires when action confirmed.
            play_token_for_voice: callable(voice_entry, token) - for voice toggle.
            voices:               the full voices dict from scan_voices().
            play_path:            callable(path) - plays a raw file path directly.
        """
        self._items                = items
        self._config               = config
        self._save                 = save_config
        self._play                 = play_token
        self._play_for_voice       = play_token_for_voice
        self._play_path            = play_path
        self._voices               = voices or {}
        self._on_action            = on_action

        self._state      = STATE_IDLE
        self._index      = 0
        self._last_event = None

    # ------------------------------------------------------------------
    # Public API
    # ------------------------------------------------------------------

    @property
    def active(self):
        """True when the menu is open."""
        return self._state == STATE_MENU

    def enter(self):
        """Open the menu."""
        self._state      = STATE_MENU
        self._index      = 0
        self._last_event = time.monotonic()
        print("Menu: entered")
        self._play("menu.enter")
        self._speak_current()

    def handle_event(self, key, press_type):
        """Process a button event while menu is active.

        Any long press exits the menu.
        Short PLUS/MINUS scrolls. Short ANNOUNCE confirms.

        Returns:
            True if the event was consumed by the menu.
        """
        if self._state != STATE_MENU:
            return False

        self._last_event = time.monotonic()

        if press_type == "long":
            print(f"Menu: long-press exit (key={key})")
            self._exit()
            return True

        if key == PLUS and press_type == "short":
            self._scroll(1)
            return True

        if key == MINUS and press_type == "short":
            self._scroll(-1)
            return True

        if key == ANNOUNCE and press_type == "short":
            print(f"Menu: confirm on '{self._items[self._index]['id']}'")
            self._confirm()
            return True

        return True  # consume all events while menu is open

    def tick(self):
        """Call from main loop every iteration to check inactivity timeout."""
        if self._state != STATE_MENU:
            return
        if (time.monotonic() - self._last_event) >= INACTIVITY_TIMEOUT:
            print("Menu: inactivity timeout, exiting")
            self._exit()

    # ------------------------------------------------------------------
    # Internal
    # ------------------------------------------------------------------

    def _scroll(self, direction):
        self._index = (self._index + direction) % len(self._items)
        item = self._items[self._index]
        print(f"Menu: scroll to [{self._index}] '{item['id']}'")
        self._speak_current()

    def _speak_current(self):
        item = self._items[self._index]
        self._play(item["audio_token"])

    def _confirm(self):
        item = self._items[self._index]

        if item["type"] == "action":
            self._exit(silent=True)
            self._on_action(item["action"])

        elif item["type"] == "toggle":
            self._cycle_toggle(item)

    def _cycle_toggle(self, item):
        options = item["options"]
        if not options:
            print(f"Menu: toggle '{item['id']}' has no options")
            return

        config_key = item["config_key"]
        current    = self._config.get(config_key)

        current_idx = 0
        for i, opt in enumerate(options):
            if opt["value"] == current:
                current_idx = i
                break

        next_idx   = (current_idx + 1) % len(options)
        next_opt   = options[next_idx]
        next_value = next_opt["value"]

        self._config[config_key] = next_value
        self._save(self._config)
        print(f"Menu: {config_key} {current!r} -> {next_value!r}")

        if item["id"] == "voice":
            target_entry = self._voices.get(next_value)
            if target_entry and self._play_for_voice:
                self._play_for_voice(target_entry, "voice.name")
            else:
                self._play(next_opt["audio_token"])
            self._on_action("reload_voice")

        elif item["id"] == "mode":
            self._on_action("reload_mode")

        elif item["id"] == "alarm_tone":
            # Play index number then tone 3 times as preview
            index = next_opt.get("index", 0)
            self._play(f"number_words.{index}")
            tone_path = next_opt.get("path")
            if tone_path and self._play_path:
                for _ in range(3):
                    self._play_path(tone_path)

        else:
            self._play(next_opt["audio_token"])

    def _exit(self, silent=False):
        self._state = STATE_IDLE
        if not silent:
            self._play("menu.exit")
        print("Menu: exited")

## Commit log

2026-02-20 Enclosure (#2)
    * add enclosure files
    * add pt
    * add circuit fritzing layout
    * add pot import
    [arcade_button.scad, clock.scad, cone_speaker.scad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]
2026-04-02 feature: add prototype enclosure
    [arcade_button.scad, clock.scad, clock_components.scad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]
2026-04-02 feature: add enclosure documentation
    [clock.scad, clock_components.scad]
2026-04-03 add svg for enclosure
2026-04-04 Add updated pico and audio generation code
2026-04-05 add documentation and top level readme
    [talking_clock.fzz]
